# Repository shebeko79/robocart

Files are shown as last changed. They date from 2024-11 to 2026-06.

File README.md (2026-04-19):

### How not to build a robot:
How not to build a robot (https://youtu.be/LK63FLP5XUo)

https://youtu.be/LK63FLP5XUo

### References:
[Field Oriented Control (FOC) for stock hoverboards](https://github.com/EFeru/hoverboard-firmware-hack-FOC)

[Introduction to MaixCAM](https://wiki.sipeed.com/hardware/en/maixcam/maixcam.html)

[MaixCAM System Flashing](https://wiki.sipeed.com/hardware/en/maixcam/os.html)

[MaixPy Quick Start](https://wiki.sipeed.com/maixpy/doc/en/index.html)

[Install RNDIS driver](https://wiki.sipeed.com/hardware/en/maixsense/maixsense-a075v/install_drivers.html)

[Ultralytics quick start](https://docs.ultralytics.com/usage/python/)

[Tracking with Ultralytics](https://docs.ultralytics.com/modes/track/)

[FastSAM](https://docs.ultralytics.com/models/fast-sam/)

[Labeling Application](https://github.com/shebeko79/py_misc/tree/main/yolo_labeling)

[My YOLO train notes](https://github.com/shebeko79/py_misc/tree/main/yolo_train)

[Self-learning Tracker](https://wiki.sipeed.com/maixpy/doc/en/vision/self_learn_detector.html)

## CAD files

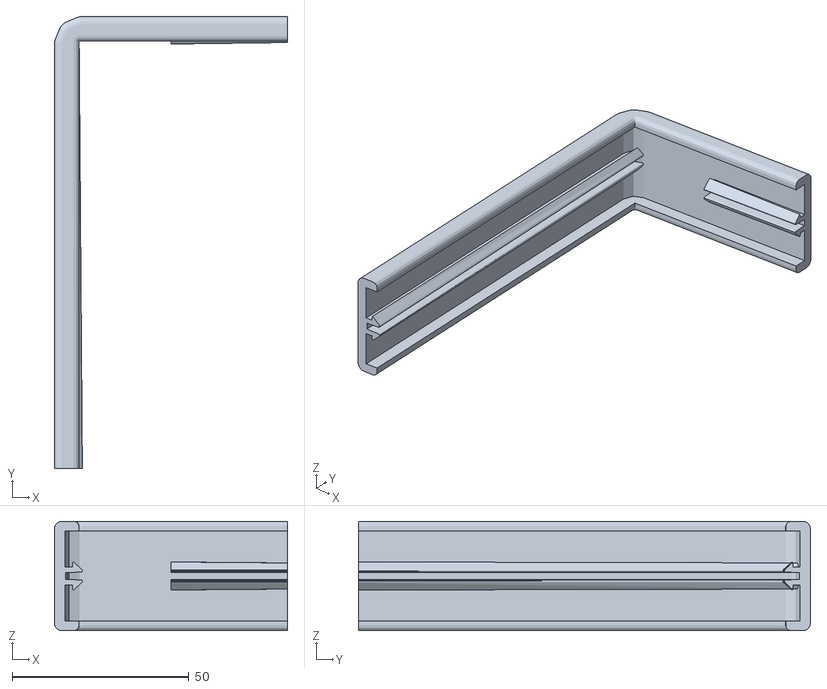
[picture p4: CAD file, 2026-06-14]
model/cover_back.stl
66.1 x 128.0 x 31.0

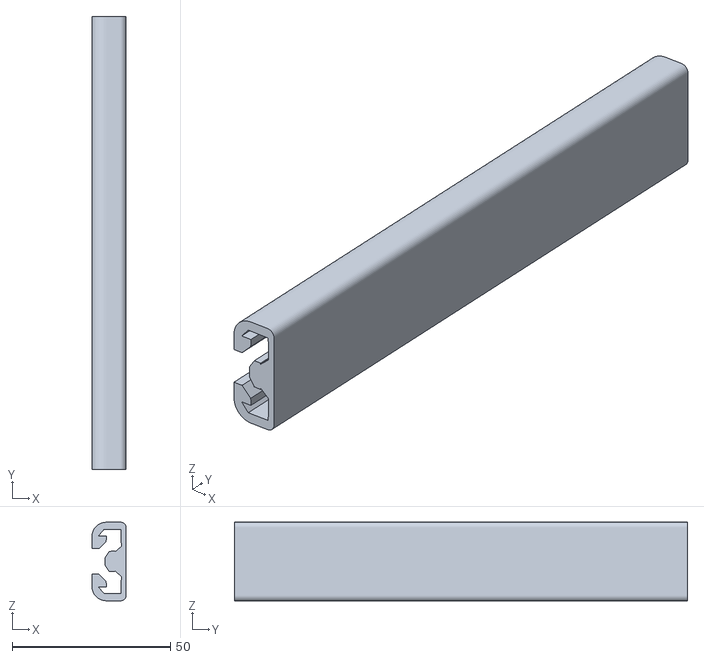
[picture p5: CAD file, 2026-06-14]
model/cover_clipsed_143.stl
10.8 x 143.0 x 24.8

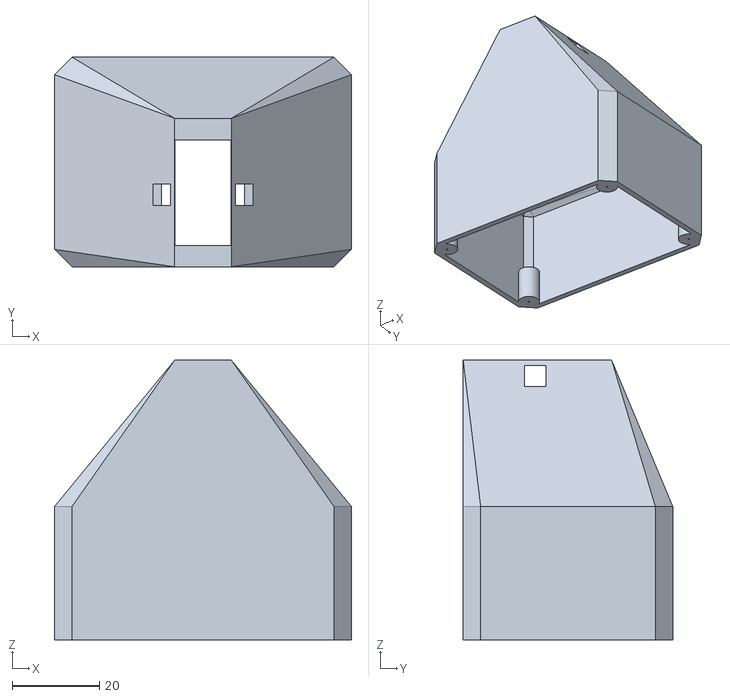
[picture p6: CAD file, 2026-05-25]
model/base.stl
68.0 x 48.0 x 64.0

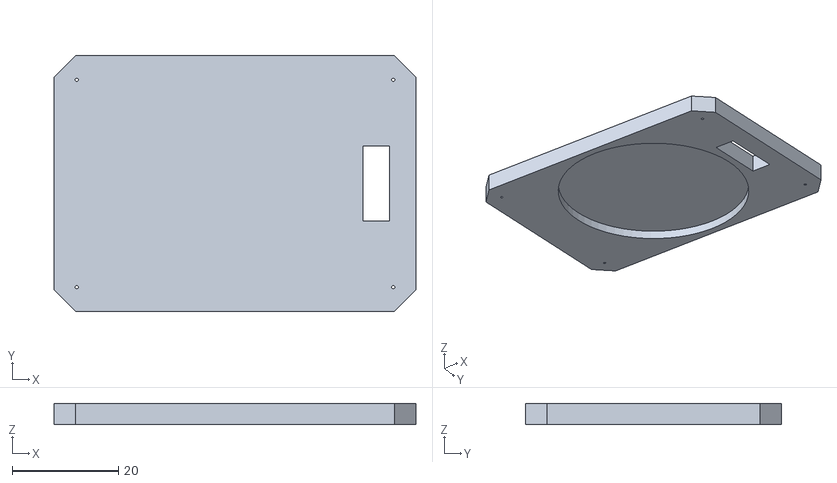
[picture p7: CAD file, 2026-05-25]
model/base_lid.stl
68.0 x 48.0 x 4.00

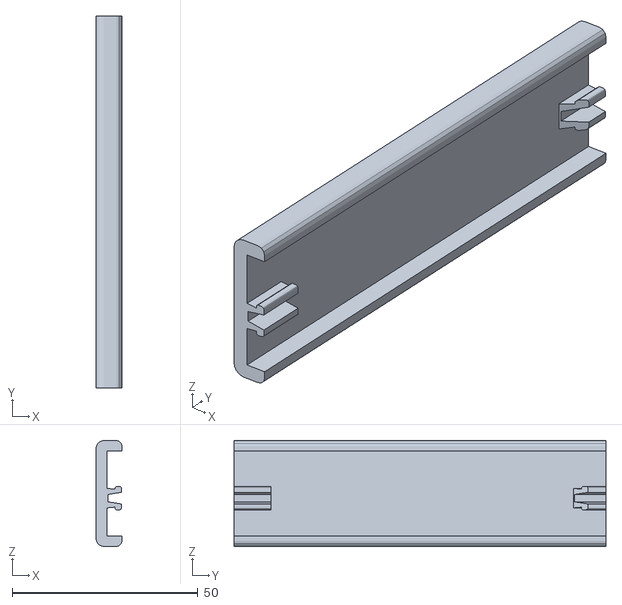
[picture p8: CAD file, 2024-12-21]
model/cover_clipsed_10.stl
7.00 x 100.0 x 28.5

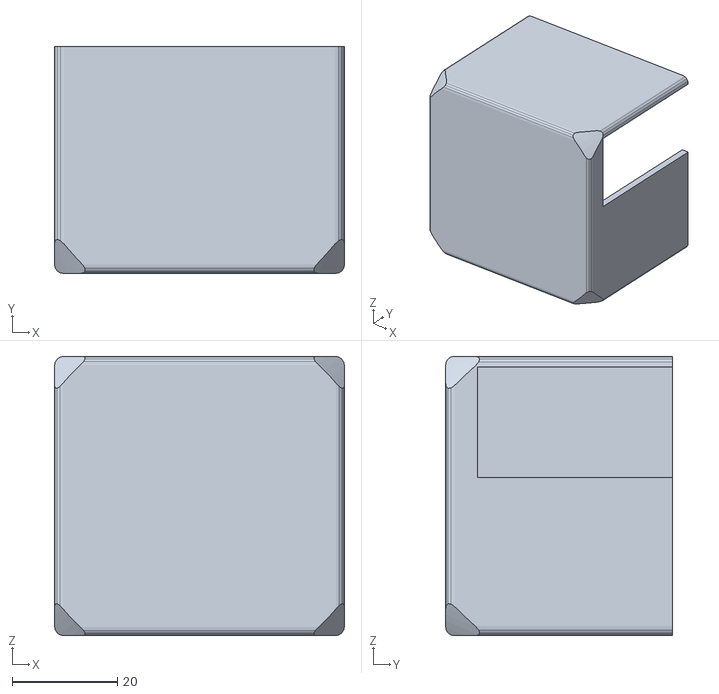
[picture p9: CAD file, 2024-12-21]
model/cover_front.stl
55.0 x 43.0 x 53.0

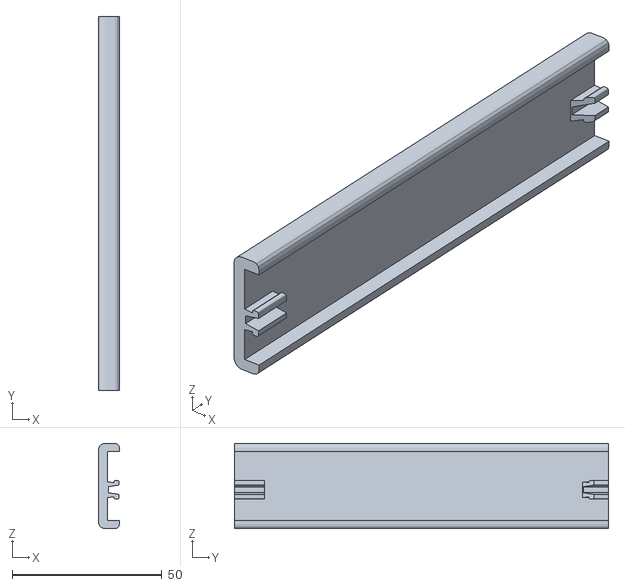
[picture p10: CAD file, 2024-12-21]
model/cover_clipsed_125.stl
7.00 x 125.0 x 28.5

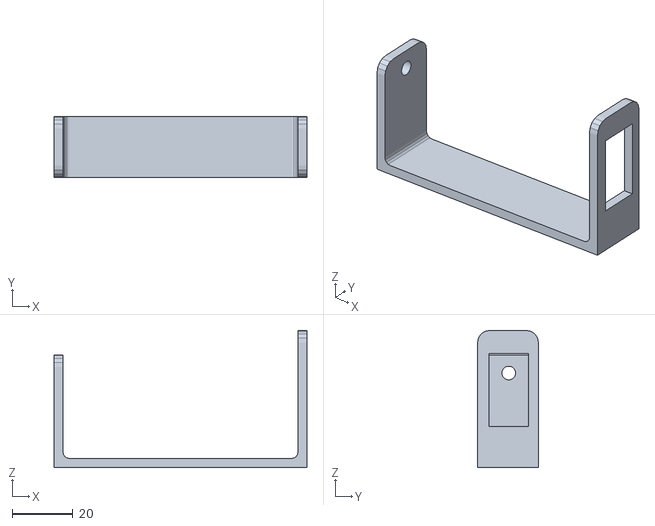
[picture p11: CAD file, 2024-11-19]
model/pan.stl
83.0 x 20.0 x 45.0

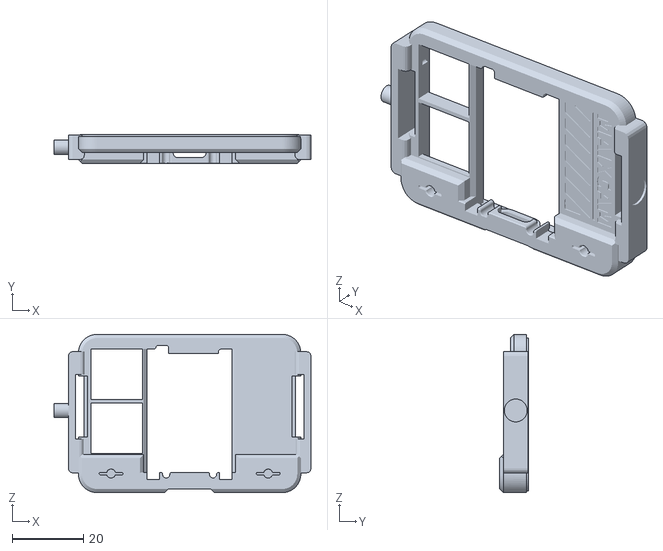
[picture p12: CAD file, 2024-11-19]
model/tilt.stl
72.0 x 8.00 x 44.3

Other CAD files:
model/2020_cover.blend
model/pantilt.blend

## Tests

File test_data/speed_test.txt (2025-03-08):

;0kg free wheel
L: time=285560 cur_speed=0.00 PWM=0.10
L: time=285611 cur_speed=0.02 PWM=0.10
L: time=285660 cur_speed=0.08 PWM=0.10
L: time=285710 cur_speed=0.14 PWM=0.10
L: time=285760 cur_speed=0.21 PWM=0.10
L: time=285810 cur_speed=0.28 PWM=0.10
L: time=285860 cur_speed=0.33 PWM=0.10
L: time=285910 cur_speed=0.40 PWM=0.10
L: time=285960 cur_speed=0.47 PWM=0.10
L: time=286010 cur_speed=0.53 PWM=0.10
L: time=286060 cur_speed=0.60 PWM=0.10
L: time=286110 cur_speed=0.65 PWM=0.10
L: time=286160 cur_speed=0.65 PWM=0.10
L: time=286210 cur_speed=0.65 PWM=0.10
L: time=286260 cur_speed=0.65 PWM=0.10
L: time=286310 cur_speed=0.65 PWM=0.10
L: time=286360 cur_speed=0.65 PWM=0.10
L: time=286410 cur_speed=0.65 PWM=0.10
L: time=286460 cur_speed=0.65 PWM=0.10
L: time=286510 cur_speed=0.65 PWM=0.10
L: time=286560 cur_speed=0.65 PWM=0.10
L: time=286610 cur_speed=0.63 PWM=0.10
L: time=286660 cur_speed=0.65 PWM=0.10
L: time=286710 cur_speed=0.65 PWM=0.10
L: time=286760 cur_speed=0.65 PWM=0.10
L: time=286810 cur_speed=0.65 PWM=0.10
L: time=286860 cur_speed=0.65 PWM=0.10
L: time=286910 cur_speed=0.63 PWM=0.10
L: time=286960 cur_speed=0.65 PWM=0.10
L: time=287010 cur_speed=0.65 PWM=0.10
L: time=287060 cur_speed=0.65 PWM=0.10
L: time=287110 cur_speed=0.65 PWM=0.10
L: time=287160 cur_speed=0.65 PWM=0.10
L: time=287210 cur_speed=0.65 PWM=0.10
L: time=287260 cur_speed=0.65 PWM=0.10
L: time=287310 cur_speed=0.65 PWM=0.10
L: time=287360 cur_speed=0.65 PWM=0.10
L: time=287410 cur_speed=0.65 PWM=0.10
L: time=287460 cur_speed=0.65 PWM=0.10
L: time=287510 cur_speed=0.63 PWM=0.10
L: time=287560 cur_speed=0.65 PWM=0.00
L: time=287610 cur_speed=0.63 PWM=0.00
L: time=287660 cur_speed=0.61 PWM=0.00
L: time=287710 cur_speed=0.60 PWM=0.00
L: time=287760 cur_speed=0.55 PWM=0.00
L: time=287810 cur_speed=0.51 PWM=0.00
L: time=287860 cur_speed=0.44 PWM=0.00
L: time=287910 cur_speed=0.37 PWM=0.00
L: time=287960 cur_speed=0.31 PWM=0.00
L: time=288010 cur_speed=0.24 PWM=0.00
L: time=288060 cur_speed=0.17 PWM=0.00
L: time=288110 cur_speed=0.12 PWM=0.00
L: time=288160 cur_speed=0.07 PWM=0.00
L: time=288210 cur_speed=0.03 PWM=0.00
L: time=288260 cur_speed=0.01 PWM=0.00

L: time=293461 cur_speed=0.00 PWM=0.20
L: time=293512 cur_speed=0.02 PWM=0.20
L: time=293562 cur_speed=0.12 PWM=0.20
L: time=293612 cur_speed=0.22 PWM=0.20
L: time=293662 cur_speed=0.33 PWM=0.20
L: time=293712 cur_speed=0.46 PWM=0.20
L: time=293762 cur_speed=0.58 PWM=0.20
L: time=293812 cur_speed=0.69 PWM=0.20
L: time=293862 cur_speed=0.81 PWM=0.20
L: time=293912 cur_speed=0.92 PWM=0.20
L: time=293962 cur_speed=1.04 PWM=0.20
L: time=294012 cur_speed=1.13 PWM=0.20
L: time=294062 cur_speed=1.14 PWM=0.20
L: time=294112 cur_speed=1.14 PWM=0.20
L: time=294162 cur_speed=1.15 PWM=0.20
L: time=294212 cur_speed=1.15 PWM=0.20
L: time=294262 cur_speed=1.15 PWM=0.20
L: time=294312 cur_speed=1.15 PWM=0.20
L: time=294362 cur_speed=1.15 PWM=0.20
L: time=294412 cur_speed=1.15 PWM=0.20
L: time=294462 cur_speed=1.15 PWM=0.20
L: time=294512 cur_speed=1.15 PWM=0.20
L: time=294562 cur_speed=1.15 PWM=0.20
L: time=294612 cur_speed=1.15 PWM=0.20
L: time=294662 cur_speed=1.15 PWM=0.20
L: time=294712 cur_speed=1.15 PWM=0.20
L: time=294762 cur_speed=1.15 PWM=0.20
L: time=294812 cur_speed=1.15 PWM=0.20
L: time=294862 cur_speed=1.15 PWM=0.20
L: time=294912 cur_speed=1.15 PWM=0.20
L: time=294962 cur_speed=1.15 PWM=0.20
L: time=295012 cur_speed=1.15 PWM=0.20
L: time=295062 cur_speed=1.15 PWM=0.20
L: time=295112 cur_speed=1.15 PWM=0.20
L: time=295162 cur_speed=1.15 PWM=0.20
L: time=295212 cur_speed=1.15 PWM=0.20
L: time=295262 cur_speed=1.15 PWM=0.20
L: time=295312 cur_speed=1.15 PWM=0.20
L: time=295362 cur_speed=1.15 PWM=0.20
L: time=295412 cur_speed=1.15 PWM=0.20
L: time=295462 cur_speed=1.15 PWM=0.00
L: time=295512 cur_speed=1.14 PWM=0.00
L: time=295562 cur_speed=1.12 PWM=0.00
L: time=295612 cur_speed=1.09 PWM=0.00
L: time=295662 cur_speed=1.05 PWM=0.00
L: time=295712 cur_speed=0.98 PWM=0.00
L: time=295762 cur_speed=0.91 PWM=0.00
L: time=295812 cur_speed=0.83 PWM=0.00
L: time=295862 cur_speed=0.73 PWM=0.00
L: time=295912 cur_speed=0.62 PWM=0.00
L: time=295962 cur_speed=0.50 PWM=0.00
L: time=296012 cur_speed=0.39 PWM=0.00
L: time=296062 cur_speed=0.30 PWM=0.00
L: time=296112 cur_speed=0.22 PWM=0.00
L: time=296162 cur_speed=0.15 PWM=0.00
L: time=296212 cur_speed=0.09 PWM=0.00
L: time=296262 cur_speed=0.06 PWM=0.00
L: time=296312 cur_speed=0.02 PWM=0.00
L: time=296362 cur_speed=0.01 PWM=0.00

L: time=299913 cur_speed=0.00 PWM=0.30
L: time=299964 cur_speed=0.02 PWM=0.30
L: time=300014 cur_speed=0.13 PWM=0.30
L: time=300064 cur_speed=0.28 PWM=0.30
L: time=300114 cur_speed=0.44 PWM=0.30
L: time=300164 cur_speed=0.61 PWM=0.30
L: time=300214 cur_speed=0.77 PWM=0.30
L: time=300264 cur_speed=0.93 PWM=0.30
L: time=300314 cur_speed=1.09 PWM=0.30
L: time=300364 cur_speed=1.27 PWM=0.30
L: time=300414 cur_speed=1.43 PWM=0.30
L: time=300464 cur_speed=1.57 PWM=0.30
L: time=300514 cur_speed=1.61 PWM=0.30
L: time=300564 cur_speed=1.64 PWM=0.30
L: time=300614 cur_speed=1.64 PWM=0.30
L: time=300664 cur_speed=1.63 PWM=0.30
L: time=300714 cur_speed=1.63 PWM=0.30
L: time=300764 cur_speed=1.64 PWM=0.30
L: time=300814 cur_speed=1.64 PWM=0.30
L: time=300864 cur_speed=1.63 PWM=0.30
L: time=300913 cur_speed=1.63 PWM=0.30
L: time=300964 cur_speed=1.64 PWM=0.30
L: time=301014 cur_speed=1.64 PWM=0.30
L: time=301064 cur_speed=1.63 PWM=0.30
L: time=301114 cur_speed=1.63 PWM=0.30
L: time=301164 cur_speed=1.64 PWM=0.30
L: time=301214 cur_speed=1.63 PWM=0.30
L: time=301264 cur_speed=1.63 PWM=0.30
L: time=301314 cur_speed=1.63 PWM=0.30
L: time=301364 cur_speed=1.64 PWM=0.30
L: time=301414 cur_speed=1.64 PWM=0.30
L: time=301464 cur_speed=1.63 PWM=0.30
L: time=301514 cur_speed=1.63 PWM=0.30
L: time=301564 cur_speed=1.64 PWM=0.30
L: time=301614 cur_speed=1.64 PWM=0.30
L: time=301664 cur_speed=1.63 PWM=0.30
L: time=301714 cur_speed=1.64 PWM=0.30
L: time=301764 cur_speed=1.64 PWM=0.30
L: time=301814 cur_speed=1.63 PWM=0.30
L: time=301864 cur_speed=1.63 PWM=0.30
L: time=301913 cur_speed=1.63 PWM=0.00
L: time=301963 cur_speed=1.63 PWM=0.00
L: time=302013 cur_speed=1.61 PWM=0.00
L: time=302063 cur_speed=1.57 PWM=0.00
L: time=302113 cur_speed=1.52 PWM=0.00
L: time=302163 cur_speed=1.46 PWM=0.00
L: time=302213 cur_speed=1.37 PWM=0.00
L: time=302263 cur_speed=1.28 PWM=0.00
L: time=302313 cur_speed=1.18 PWM=0.00
L: time=302364 cur_speed=1.06 PWM=0.00
L: time=302413 cur_speed=0.92 PWM=0.00
L: time=302463 cur_speed=0.80 PWM=0.00
L: time=302513 cur_speed=0.66 PWM=0.00
L: time=302563 cur_speed=0.53 PWM=0.00
L: time=302613 cur_speed=0.41 PWM=0.00
L: time=302663 cur_speed=0.32 PWM=0.00
L: time=302713 cur_speed=0.23 PWM=0.00
L: time=302763 cur_speed=0.16 PWM=0.00
L: time=302813 cur_speed=0.10 PWM=0.00
L: time=302863 cur_speed=0.06 PWM=0.00
L: time=302913 cur_speed=0.02 PWM=0.00
L: time=302963 cur_speed=0.01 PWM=0.00

L: time=307314 cur_speed=0.00 PWM=0.40
L: time=307364 cur_speed=0.02 PWM=0.40
L: time=307414 cur_speed=0.13 PWM=0.40
L: time=307464 cur_speed=0.31 PWM=0.40
L: time=307514 cur_speed=0.52 PWM=0.40
L: time=307564 cur_speed=0.73 PWM=0.40
L: time=307614 cur_speed=0.95 PWM=0.40
L: time=307664 cur_speed=1.15 PWM=0.40
L: time=307714 cur_speed=1.37 PWM=0.40
L: time=307764 cur_speed=1.58 PWM=0.40
L: time=307814 cur_speed=1.79 PWM=0.40
L: time=307864 cur_speed=1.98 PWM=0.40
L: time=307914 cur_speed=2.07 PWM=0.40
L: time=307964 cur_speed=2.11 PWM=0.40
L: time=308014 cur_speed=2.11 PWM=0.40
L: time=308064 cur_speed=2.11 PWM=0.40
L: time=308114 cur_speed=2.11 PWM=0.40
L: time=308164 cur_speed=2.11 PWM=0.40
L: time=308214 cur_speed=2.10 PWM=0.40
L: time=308264 cur_speed=2.11 PWM=0.40
L: time=308314 cur_speed=2.11 PWM=0.40
L: time=308364 cur_speed=2.10 PWM=0.40
L: time=308414 cur_speed=2.11 PWM=0.40
L: time=308464 cur_speed=2.11 PWM=0.40
L: time=308514 cur_speed=2.11 PWM=0.40
L: time=308564 cur_speed=2.11 PWM=0.40
L: time=308614 cur_speed=2.10 PWM=0.40
L: time=308664 cur_speed=2.11 PWM=0.40
L: time=308714 cur_speed=2.11 PWM=0.40
L: time=308764 cur_speed=2.11 PWM=0.40
L: time=308814 cur_speed=2.11 PWM=0.40
L: time=308864 cur_speed=2.11 PWM=0.40
L: time=308914 cur_speed=2.11 PWM=0.40
L: time=308964 cur_speed=2.11 PWM=0.40
L: time=309014 cur_speed=2.10 PWM=0.40
L: time=309064 cur_speed=2.11 PWM=0.40
L: time=309114 cur_speed=2.11 PWM=0.40
L: time=309164 cur_speed=2.11 PWM=0.40
L: time=309214 cur_speed=2.11 PWM=0.40
L: time=309264 cur_speed=2.11 PWM=0.40
L: time=309314 cur_speed=2.11 PWM=0.00
L: time=309364 cur_speed=2.11 PWM=0.00
L: time=309414 cur_speed=2.07 PWM=0.00
L: time=309464 cur_speed=2.04 PWM=0.00
L: time=309514 cur_speed=1.99 PWM=0.00
L: time=309564 cur_speed=1.92 PWM=0.00
L: time=309614 cur_speed=1.84 PWM=0.00
L: time=309664 cur_speed=1.73 PWM=0.00
L: time=309714 cur_speed=1.63 PWM=0.00
L: time=309764 cur_speed=1.51 PWM=0.00
L: time=309814 cur_speed=1.36 PWM=0.00
L: time=309864 cur_speed=1.22 PWM=0.00
L: time=309914 cur_speed=1.07 PWM=0.00
L: time=309964 cur_speed=0.93 PWM=0.00
L: time=310014 cur_speed=0.78 PWM=0.00
L: time=310064 cur_speed=0.66 PWM=0.00
L: time=310114 cur_speed=0.53 PWM=0.00
L: time=310164 cur_speed=0.41 PWM=0.00
L: time=310214 cur_speed=0.32 PWM=0.00
L: time=310264 cur_speed=0.23 PWM=0.00
L: time=310314 cur_speed=0.16 PWM=0.00
L: time=310364 cur_speed=0.10 PWM=0.00
L: time=310414 cur_speed=0.06 PWM=0.00
L: time=310464 cur_speed=0.02 PWM=0.00

L: time=314765 cur_speed=0.00 PWM=0.50
L: time=314816 cur_speed=0.02 PWM=0.50
L: time=314866 cur_speed=0.13 PWM=0.50
L: time=314916 cur_speed=0.33 PWM=0.50
L: time=314965 cur_speed=0.58 PWM=0.50
L: time=315015 cur_speed=0.83 PWM=0.50
L: time=315065 cur_speed=1.08 PWM=0.50
L: time=315116 cur_speed=1.34 PWM=0.50
L: time=315165 cur_speed=1.59 PWM=0.50
L: time=315216 cur_speed=1.84 PWM=0.50
L: time=315266 cur_speed=2.10 PWM=0.50
L: time=315315 cur_speed=2.33 PWM=0.50
L: time=315365 cur_speed=2.47 PWM=0.50
L: time=315415 cur_speed=2.52 PWM=0.50
L: time=315465 cur_speed=2.54 PWM=0.50
L: time=315515 cur_speed=2.54 PWM=0.50
L: time=315565 cur_speed=2.54 PWM=0.50
L: time=315615 cur_speed=2.54 PWM=0.50
L: time=315665 cur_speed=2.54 PWM=0.50
L: time=315715 cur_speed=2.52 PWM=0.50
L: time=315765 cur_speed=2.52 PWM=0.50
L: time=315815 cur_speed=2.52 PWM=0.50
L: time=315865 cur_speed=2.52 PWM=0.50
L: time=315915 cur_speed=2.52 PWM=0.50
L: time=315965 cur_speed=2.52 PWM=0.50
L: time=316015 cur_speed=2.52 PWM=0.50
L: time=316065 cur_speed=2.52 PWM=0.50
L: time=316115 cur_speed=2.52 PWM=0.50
L: time=316165 cur_speed=2.52 PWM=0.50
L: time=316215 cur_speed=2.52 PWM=0.50
L: time=316265 cur_speed=2.52 PWM=0.50
L: time=316315 cur_speed=2.52 PWM=0.50
L: time=316365 cur_speed=2.52 PWM=0.50
L: time=316415 cur_speed=2.52 PWM=0.50
L: time=316465 cur_speed=2.52 PWM=0.50
L: time=316515 cur_speed=2.54 PWM=0.50
L: time=316565 cur_speed=2.52 PWM=0.50
L: time=316616 cur_speed=2.52 PWM=0.50
L: time=316665 cur_speed=2.54 PWM=0.50
L: time=316715 cur_speed=2.54 PWM=0.50
L: time=316765 cur_speed=2.54 PWM=0.00
L: time=316815 cur_speed=2.52 PWM=0.00
L: time=316865 cur_speed=2.50 PWM=0.00
L: time=316915 cur_speed=2.47 PWM=0.00
L: time=316965 cur_speed=2.41 PWM=0.00
L: time=317015 cur_speed=2.34 PWM=0.00
L: time=317065 cur_speed=2.25 PWM=0.00
L: time=317115 cur_speed=2.14 PWM=0.00
L: time=317165 cur_speed=2.02 PWM=0.00
L: time=317215 cur_speed=1.89 PWM=0.00
L: time=317265 cur_speed=1.74 PWM=0.00
L: time=317315 cur_speed=1.58 PWM=0.00
L: time=317365 cur_speed=1.42 PWM=0.00
L: time=317415 cur_speed=1.27 PWM=0.00
L: time=317465 cur_speed=1.13 PWM=0.00
L: time=317515 cur_speed=0.98 PWM=0.00
L: time=317565 cur_speed=0.84 PWM=0.00
L: time=317615 cur_speed=0.69 PWM=0.00
L: time=317665 cur_speed=0.58 PWM=0.00
L: time=317715 cur_speed=0.46 PWM=0.00
L: time=317765 cur_speed=0.36 PWM=0.00
L: time=317815 cur_speed=0.27 PWM=0.00
L: time=317865 cur_speed=0.20 PWM=0.00
L: time=317915 cur_speed=0.13 PWM=0.00
L: time=317965 cur_speed=0.08 PWM=0.00
L: time=318015 cur_speed=0.05 PWM=0.00
L: time=318065 cur_speed=0.02 PWM=0.00
L: time=318115 cur_speed=0.02 PWM=0.00

L: time=324166 cur_speed=0.00 PWM=0.60
L: time=324217 cur_speed=0.02 PWM=0.60
L: time=324267 cur_speed=0.13 PWM=0.60
L: time=324316 cur_speed=0.33 PWM=0.60
L: time=324367 cur_speed=0.61 PWM=0.60
L: time=324417 cur_speed=0.90 PWM=0.60
L: time=324467 cur_speed=1.20 PWM=0.60
L: time=324516 cur_speed=1.50 PWM=0.60
L: time=324566 cur_speed=1.79 PWM=0.60
L: time=324617 cur_speed=2.09 PWM=0.60
L: time=324667 cur_speed=2.39 PWM=0.60
L: time=324717 cur_speed=2.66 PWM=0.60
L: time=324766 cur_speed=2.85 PWM=0.60
L: time=324816 cur_speed=2.94 PWM=0.60
L: time=324867 cur_speed=2.96 PWM=0.60
L: time=324917 cur_speed=2.97 PWM=0.60
L: time=324967 cur_speed=2.96 PWM=0.60
L: time=325017 cur_speed=2.96 PWM=0.60
L: time=325067 cur_speed=2.96 PWM=0.60
L: time=325117 cur_speed=2.97 PWM=0.60
L: time=325167 cur_speed=2.96 PWM=0.60
L: time=325216 cur_speed=2.96 PWM=0.60
L: time=325267 cur_speed=2.96 PWM=0.60
L: time=325317 cur_speed=2.97 PWM=0.60
L: time=325366 cur_speed=2.96 PWM=0.60
L: time=325417 cur_speed=2.96 PWM=0.60
L: time=325466 cur_speed=2.96 PWM=0.60
L: time=325516 cur_speed=2.96 PWM=0.60
L: time=325567 cur_speed=2.96 PWM=0.60
L: time=325616 cur_speed=2.96 PWM=0.60
L: time=325667 cur_speed=2.97 PWM=0.60
L: time=325717 cur_speed=2.97 PWM=0.60
L: time=325767 cur_speed=2.96 PWM=0.60
L: time=325817 cur_speed=2.96 PWM=0.60
L: time=325867 cur_speed=2.96 PWM=0.60
L: time=325917 cur_speed=2.96 PWM=0.60
L: time=325967 cur_speed=2.96 PWM=0.60
L: time=326017 cur_speed=2.96 PWM=0.60
L: time=326067 cur_speed=2.96 PWM=0.60
L: time=326116 cur_speed=2.96 PWM=0.60
L: time=326166 cur_speed=2.96 PWM=0.00
L: time=326216 cur_speed=2.95 PWM=0.00
L: time=326266 cur_speed=2.93 PWM=0.00
L: time=326316 cur_speed=2.89 PWM=0.00
L: time=326366 cur_speed=2.84 PWM=0.00
L: time=326416 cur_speed=2.75 PWM=0.00
L: time=326466 cur_speed=2.66 PWM=0.00
L: time=326516 cur_speed=2.56 PWM=0.00
L: time=326566 cur_speed=2.42 PWM=0.00
L: time=326616 cur_speed=2.28 PWM=0.00
L: time=326666 cur_speed=2.13 PWM=0.00
L: time=326716 cur_speed=1.95 PWM=0.00
L: time=326766 cur_speed=1.80 PWM=0.00
L: time=326816 cur_speed=1.63 PWM=0.00
L: time=326866 cur_speed=1.48 PWM=0.00
L: time=326916 cur_speed=1.31 PWM=0.00
L: time=326966 cur_speed=1.16 PWM=0.00
L: time=327016 cur_speed=1.03 PWM=0.00
L: time=327066 cur_speed=0.89 PWM=0.00
L: time=327116 cur_speed=0.75 PWM=0.00
L: time=327166 cur_speed=0.62 PWM=0.00
L: time=327216 cur_speed=0.51 PWM=0.00
L: time=327266 cur_speed=0.39 PWM=0.00
L: time=327316 cur_speed=0.30 PWM=0.00
L: time=327366 cur_speed=0.22 PWM=0.00
L: time=327416 cur_speed=0.15 PWM=0.00
L: time=327466 cur_speed=0.10 PWM=0.00
L: time=327516 cur_speed=0.06 PWM=0.00
L: time=327566 cur_speed=0.02 PWM=0.00
L: time=327616 cur_speed=0.01 PWM=0.00

L: time=331117 cur_speed=0.00 PWM=0.70
L: time=331167 cur_speed=0.01 PWM=0.70
L: time=331217 cur_speed=0.13 PWM=0.70
L: time=331267 cur_speed=0.33 PWM=0.70
L: time=331317 cur_speed=0.62 PWM=0.70
L: time=331367 cur_speed=0.96 PWM=0.70
L: time=331417 cur_speed=1.29 PWM=0.70
L: time=331467 cur_speed=1.63 PWM=0.70
L: time=331517 cur_speed=1.96 PWM=0.70
L: time=331567 cur_speed=2.29 PWM=0.70
L: time=331617 cur_speed=2.63 PWM=0.70
L: time=331667 cur_speed=2.95 PWM=0.70
L: time=331717 cur_speed=3.16 PWM=0.70
L: time=331767 cur_speed=3.26 PWM=0.70
L: time=331817 cur_speed=3.28 PWM=0.70
L: time=331867 cur_speed=3.30 PWM=0.70
L: time=331917 cur_speed=3.31 PWM=0.70
L: time=331967 cur_speed=3.31 PWM=0.70
L: time=332017 cur_speed=3.30 PWM=0.70
L: time=332067 cur_speed=3.30 PWM=0.70
L: time=332117 cur_speed=3.30 PWM=0.70
L: time=332167 cur_speed=3.31 PWM=0.70
L: time=332217 cur_speed=3.31 PWM=0.70
L: time=332267 cur_speed=3.30 PWM=0.70
L: time=332317 cur_speed=3.30 PWM=0.70
L: time=332367 cur_speed=3.30 PWM=0.70
L: time=332417 cur_speed=3.31 PWM=0.70
L: time=332467 cur_speed=3.31 PWM=0.70
L: time=332517 cur_speed=3.30 PWM=0.70
L: time=332567 cur_speed=3.30 PWM=0.70
L: time=332617 cur_speed=3.30 PWM=0.70
L: time=332667 cur_speed=3.31 PWM=0.70
L: time=332717 cur_speed=3.31 PWM=0.70
L: time=332767 cur_speed=3.30 PWM=0.70
L: time=332817 cur_speed=3.30 PWM=0.70
L: time=332867 cur_speed=3.30 PWM=0.70
L: time=332917 cur_speed=3.31 PWM=0.70
L: time=332967 cur_speed=3.31 PWM=0.70
L: time=333017 cur_speed=3.30 PWM=0.70
L: time=333067 cur_speed=3.30 PWM=0.70
L: time=333117 cur_speed=3.30 PWM=0.00
L: time=333167 cur_speed=3.30 PWM=0.00
L: time=333217 cur_speed=3.27 PWM=0.00
L: time=333267 cur_speed=3.23 PWM=0.00
L: time=333317 cur_speed=3.16 PWM=0.00
L: time=333367 cur_speed=3.08 PWM=0.00
L: time=333417 cur_speed=2.99 PWM=0.00
L: time=333467 cur_speed=2.87 PWM=0.00
L: time=333517 cur_speed=2.72 PWM=0.00
L: time=333567 cur_speed=2.58 PWM=0.00
L: time=333617 cur_speed=2.41 PWM=0.00
L: time=333667 cur_speed=2.25 PWM=0.00
L: time=333717 cur_speed=2.07 PWM=0.00
L: time=333767 cur_speed=1.90 PWM=0.00
L: time=333817 cur_speed=1.73 PWM=0.00
L: time=333867 cur_speed=1.59 PWM=0.00
L: time=333917 cur_speed=1.42 PWM=0.00
L: time=333967 cur_speed=1.28 PWM=0.00
L: time=334017 cur_speed=1.12 PWM=0.00
L: time=334067 cur_speed=0.98 PWM=0.00
L: time=334117 cur_speed=0.84 PWM=0.00
L: time=334167 cur_speed=0.70 PWM=0.00
L: time=334217 cur_speed=0.56 PWM=0.00
L: time=334267 cur_speed=0.45 PWM=0.00
L: time=334317 cur_speed=0.35 PWM=0.00
L: time=334367 cur_speed=0.25 PWM=0.00
L: time=334417 cur_speed=0.17 PWM=0.00
L: time=334467 cur_speed=0.12 PWM=0.00
L: time=334517 cur_speed=0.07 PWM=0.00
L: time=334567 cur_speed=0.03 PWM=0.00
L: time=334617 cur_speed=0.01 PWM=0.00

L: time=338522 cur_speed=0.00 PWM=0.80
L: time=338573 cur_speed=0.02 PWM=0.80
L: time=338623 cur_speed=0.13 PWM=0.80
L: time=338673 cur_speed=0.33 PWM=0.80
L: time=338723 cur_speed=0.63 PWM=0.80
L: time=338773 cur_speed=0.99 PWM=0.80
L: time=338823 cur_speed=1.36 PWM=0.80
L: time=338873 cur_speed=1.74 PWM=0.80
L: time=338923 cur_speed=2.11 PWM=0.80
L: time=338973 cur_speed=2.49 PWM=0.80
L: time=339023 cur_speed=2.86 PWM=0.80
L: time=339073 cur_speed=3.22 PWM=0.80
L: time=339122 cur_speed=3.47 PWM=0.80
L: time=339173 cur_speed=3.63 PWM=0.80
L: time=339223 cur_speed=3.69 PWM=0.80
L: time=339273 cur_speed=3.71 PWM=0.80
L: time=339323 cur_speed=3.71 PWM=0.80
L: time=339373 cur_speed=3.71 PWM=0.80
L: time=339423 cur_speed=3.72 PWM=0.80
L: time=339473 cur_speed=3.71 PWM=0.80
L: time=339523 cur_speed=3.72 PWM=0.80
L: time=339573 cur_speed=3.71 PWM=0.80
L: time=339623 cur_speed=3.72 PWM=0.80
L: time=339673 cur_speed=3.71 PWM=0.80
L: time=339723 cur_speed=3.72 PWM=0.80
L: time=339773 cur_speed=3.71 PWM=0.80
L: time=339823 cur_speed=3.72 PWM=0.80
L: time=339872 cur_speed=3.71 PWM=0.80
L: time=339923 cur_speed=3.72 PWM=0.80
L: time=339973 cur_speed=3.71 PWM=0.80
L: time=340023 cur_speed=3.72 PWM=0.80
L: time=340073 cur_speed=3.71 PWM=0.80
L: time=340123 cur_speed=3.71 PWM=0.80
L: time=340173 cur_speed=3.71 PWM=0.80
L: time=340223 cur_speed=3.71 PWM=0.80
L: time=340273 cur_speed=3.71 PWM=0.80
L: time=340323 cur_speed=3.71 PWM=0.80
L: time=340373 cur_speed=3.71 PWM=0.80
L: time=340422 cur_speed=3.71 PWM=0.80
L: time=340472 cur_speed=3.71 PWM=0.80
L: time=340522 cur_speed=3.71 PWM=0.00
L: time=340573 cur_speed=3.71 PWM=0.00
L: time=340623 cur_speed=3.68 PWM=0.00
L: time=340672 cur_speed=3.64 PWM=0.00
L: time=340723 cur_speed=3.56 PWM=0.00
L: time=340772 cur_speed=3.48 PWM=0.00
L: time=340822 cur_speed=3.38 PWM=0.00
L: time=340873 cur_speed=3.26 PWM=0.00
L: time=340923 cur_speed=3.11 PWM=0.00
L: time=340973 cur_speed=2.96 PWM=0.00
L: time=341023 cur_speed=2.78 PWM=0.00
L: time=341073 cur_speed=2.59 PWM=0.00
L: time=341123 cur_speed=2.41 PWM=0.00
L: time=341172 cur_speed=2.25 PWM=0.00
L: time=341222 cur_speed=2.06 PWM=0.00
L: time=341273 cur_speed=1.90 PWM=0.00
L: time=341323 cur_speed=1.74 PWM=0.00
L: time=341372 cur_speed=1.58 PWM=0.00
L: time=341423 cur_speed=1.42 PWM=0.00
L: time=341473 cur_speed=1.28 PWM=0.00
L: time=341523 cur_speed=1.12 PWM=0.00
L: time=341573 cur_speed=0.99 PWM=0.00
L: time=341623 cur_speed=0.84 PWM=0.00
L: time=341673 cur_speed=0.71 PWM=0.00
L: time=341722 cur_speed=0.59 PWM=0.00
L: time=341773 cur_speed=0.47 PWM=0.00
L: time=341823 cur_speed=0.37 PWM=0.00
L: time=341872 cur_speed=0.28 PWM=0.00
L: time=341922 cur_speed=0.20 PWM=0.00
L: time=341972 cur_speed=0.14 PWM=0.00
L: time=342023 cur_speed=0.08 PWM=0.00
L: time=342073 cur_speed=0.05 PWM=0.00
L: time=342122 cur_speed=0.01 PWM=0.00

L: time=346473 cur_speed=0.00 PWM=0.90
L: time=346524 cur_speed=0.02 PWM=0.90
L: time=346574 cur_speed=0.13 PWM=0.90
L: time=346624 cur_speed=0.33 PWM=0.90
L: time=346674 cur_speed=0.63 PWM=0.90
L: time=346724 cur_speed=1.01 PWM=0.90
L: time=346774 cur_speed=1.42 PWM=0.90
L: time=346824 cur_speed=1.82 PWM=0.90
L: time=346874 cur_speed=2.24 PWM=0.90
L: time=346923 cur_speed=2.65 PWM=0.90
L: time=346974 cur_speed=3.05 PWM=0.90
L: time=347024 cur_speed=3.45 PWM=0.90
L: time=347074 cur_speed=3.75 PWM=0.90
L: time=347124 cur_speed=3.94 PWM=0.90
L: time=347174 cur_speed=4.03 PWM=0.90
L: time=347224 cur_speed=4.08 PWM=0.90
L: time=347274 cur_speed=4.09 PWM=0.90
L: time=347324 cur_speed=4.09 PWM=0.90
L: time=347374 cur_speed=4.08 PWM=0.90
L: time=347424 cur_speed=4.09 PWM=0.90
L: time=347474 cur_speed=4.09 PWM=0.90
L: time=347524 cur_speed=4.09 PWM=0.90
L: time=347574 cur_speed=4.08 PWM=0.90
L: time=347624 cur_speed=4.09 PWM=0.90
L: time=347673 cur_speed=4.09 PWM=0.90
L: time=347724 cur_speed=4.09 PWM=0.90
L: time=347774 cur_speed=4.08 PWM=0.90
L: time=347824 cur_speed=4.09 PWM=0.90
L: time=347874 cur_speed=4.09 PWM=0.90
L: time=347924 cur_speed=4.09 PWM=0.90
L: time=347974 cur_speed=4.09 PWM=0.90
L: time=348024 cur_speed=4.09 PWM=0.90
L: time=348074 cur_speed=4.09 PWM=0.90
L: time=348124 cur_speed=4.08 PWM=0.90
L: time=348174 cur_speed=4.09 PWM=0.90
L: time=348224 cur_speed=4.09 PWM=0.90
L: time=348274 cur_speed=4.09 PWM=0.90
L: time=348324 cur_speed=4.08 PWM=0.90
L: time=348374 cur_speed=4.09 PWM=0.90
L: time=348424 cur_speed=4.09 PWM=0.90
L: time=348473 cur_speed=4.09 PWM=0.00
L: time=348523 cur_speed=4.08 PWM=0.00
L: time=348573 cur_speed=4.06 PWM=0.00
L: time=348623 cur_speed=4.01 PWM=0.00
L: time=348673 cur_speed=3.93 PWM=0.00
L: time=348723 cur_speed=3.84 PWM=0.00
L: time=348773 cur_speed=3.75 PWM=0.00
L: time=348823 cur_speed=3.61 PWM=0.00
L: time=348873 cur_speed=3.46 PWM=0.00
L: time=348923 cur_speed=3.30 PWM=0.00
L: time=348973 cur_speed=3.11 PWM=0.00
L: time=349023 cur_speed=2.93 PWM=0.00
L: time=349073 cur_speed=2.73 PWM=0.00
L: time=349123 cur_speed=2.55 PWM=0.00
L: time=349173 cur_speed=2.37 PWM=0.00
L: time=349223 cur_speed=2.19 PWM=0.00
L: time=349273 cur_speed=2.02 PWM=0.00
L: time=349323 cur_speed=1.84 PWM=0.00
L: time=349373 cur_speed=1.68 PWM=0.00
L: time=349423 cur_speed=1.53 PWM=0.00
L: time=349474 cur_speed=1.37 PWM=0.00
L: time=349523 cur_speed=1.22 PWM=0.00
L: time=349574 cur_speed=1.07 PWM=0.00
L: time=349623 cur_speed=0.93 PWM=0.00
L: time=349674 cur_speed=0.81 PWM=0.00
L: time=349723 cur_speed=0.66 PWM=0.00
L: time=349773 cur_speed=0.53 PWM=0.00
L: time=349823 cur_speed=0.41 PWM=0.00
L: time=349874 cur_speed=0.31 PWM=0.00
L: time=349923 cur_speed=0.23 PWM=0.00
L: time=349973 cur_speed=0.16 PWM=0.00
L: time=350023 cur_speed=0.09 PWM=0.00
L: time=350073 cur_speed=0.06 PWM=0.00
L: time=350123 cur_speed=0.02 PWM=0.00
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

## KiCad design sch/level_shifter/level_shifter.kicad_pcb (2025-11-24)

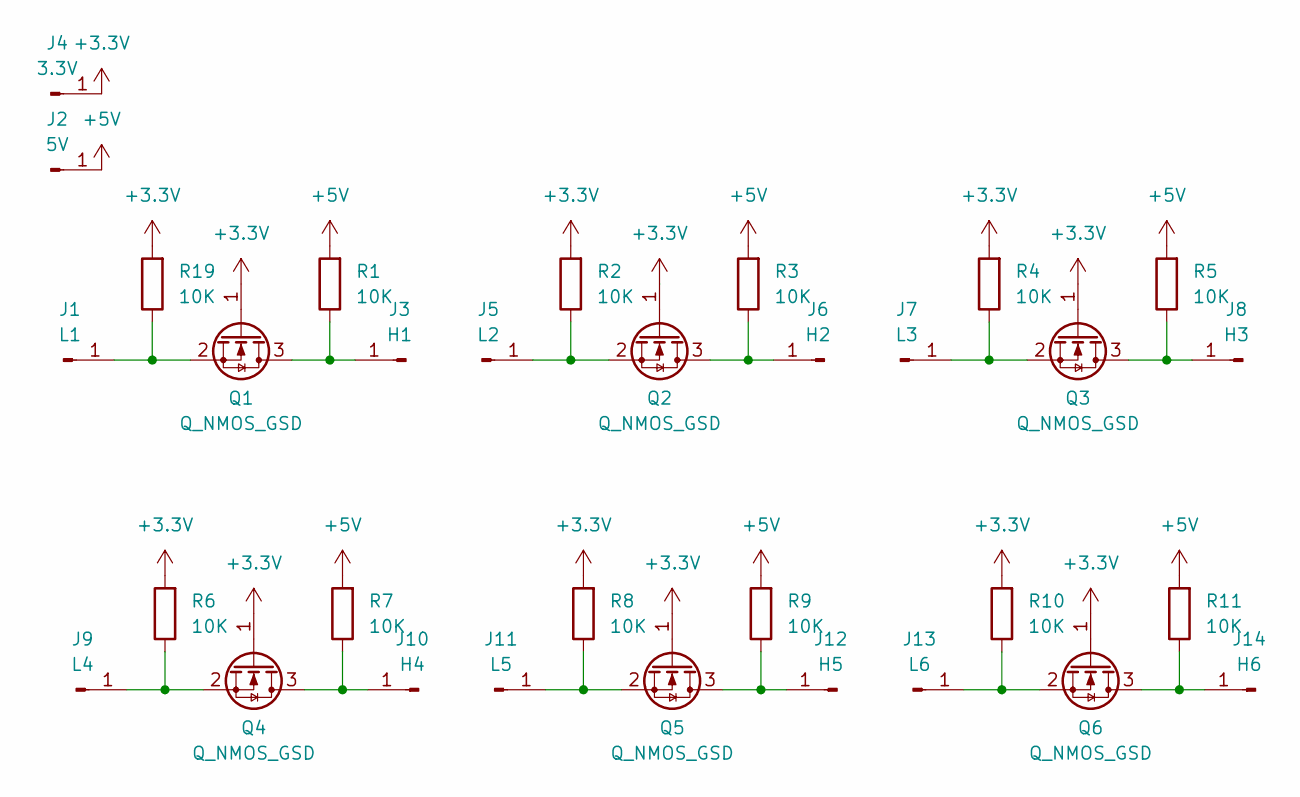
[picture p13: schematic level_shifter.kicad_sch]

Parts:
J1: L1; SolderWirePad_1x01_SMD_1x2mm
J2: 5V; SolderWirePad_1x01_SMD_1x2mm
J3: H1; SolderWirePad_1x01_SMD_1x2mm
J4: 3.3V; SolderWirePad_1x01_SMD_1x2mm
J5: L2; SolderWirePad_1x01_SMD_1x2mm
J6: H2; SolderWirePad_1x01_SMD_1x2mm
J7: L3; SolderWirePad_1x01_SMD_1x2mm
J8: H3; SolderWirePad_1x01_SMD_1x2mm
J9: L4; SolderWirePad_1x01_SMD_1x2mm
J10: H4; SolderWirePad_1x01_SMD_1x2mm
J11: L5; SolderWirePad_1x01_SMD_1x2mm
J12: H5; SolderWirePad_1x01_SMD_1x2mm
J13: L6; SolderWirePad_1x01_SMD_1x2mm
J14: H6; SolderWirePad_1x01_SMD_1x2mm
Q1, Q2, Q3, Q4, Q5, Q6: Q_NMOS_GSD; SOT-23_Handsoldering
R1, R2, R3, R4, R5, R6, R7, R8, R9, R10, R11, R19: 10K; R_0805_2012Metric

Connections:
+3.3V: J4.1, Q1.1 (G), Q2.1 (G), Q3.1 (G), Q4.1 (G), Q5.1 (G), Q6.1 (G), R2.2, R4.2, R6.2, R8.2, R10.2, R19.2
+5V: J2.1, R1.2, R3.2, R5.2, R7.2, R9.2, R11.2
unnamed: J1.1, Q1.2 (S), R19.1
unnamed: J3.1, Q1.3 (D), R1.1
unnamed: J5.1, Q2.2 (S), R2.1
unnamed: J6.1, Q2.3 (D), R3.1
unnamed: J7.1, Q3.2 (S), R4.1
unnamed: J8.1, Q3.3 (D), R5.1
unnamed: J9.1, Q4.2 (S), R6.1
unnamed: J10.1, Q4.3 (D), R7.1
unnamed: J11.1, Q5.2 (S), R8.1
unnamed: J12.1, Q5.3 (D), R9.1
unnamed: J13.1, Q6.2 (S), R10.1
unnamed: J14.1, Q6.3 (D), R11.1

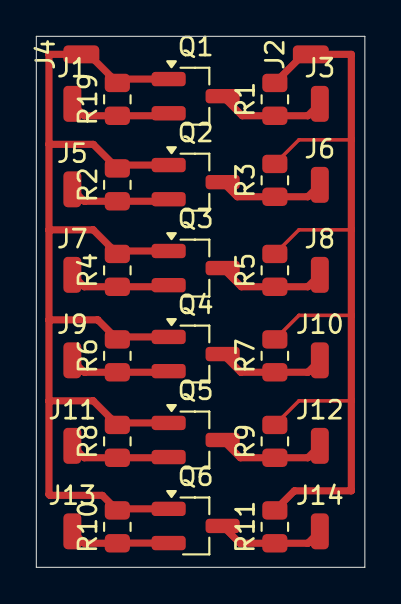
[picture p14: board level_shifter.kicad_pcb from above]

Board: 4 copper layers, 18.2 x 29.5 mm, 32 parts (0 on the bottom side), 14 nets.

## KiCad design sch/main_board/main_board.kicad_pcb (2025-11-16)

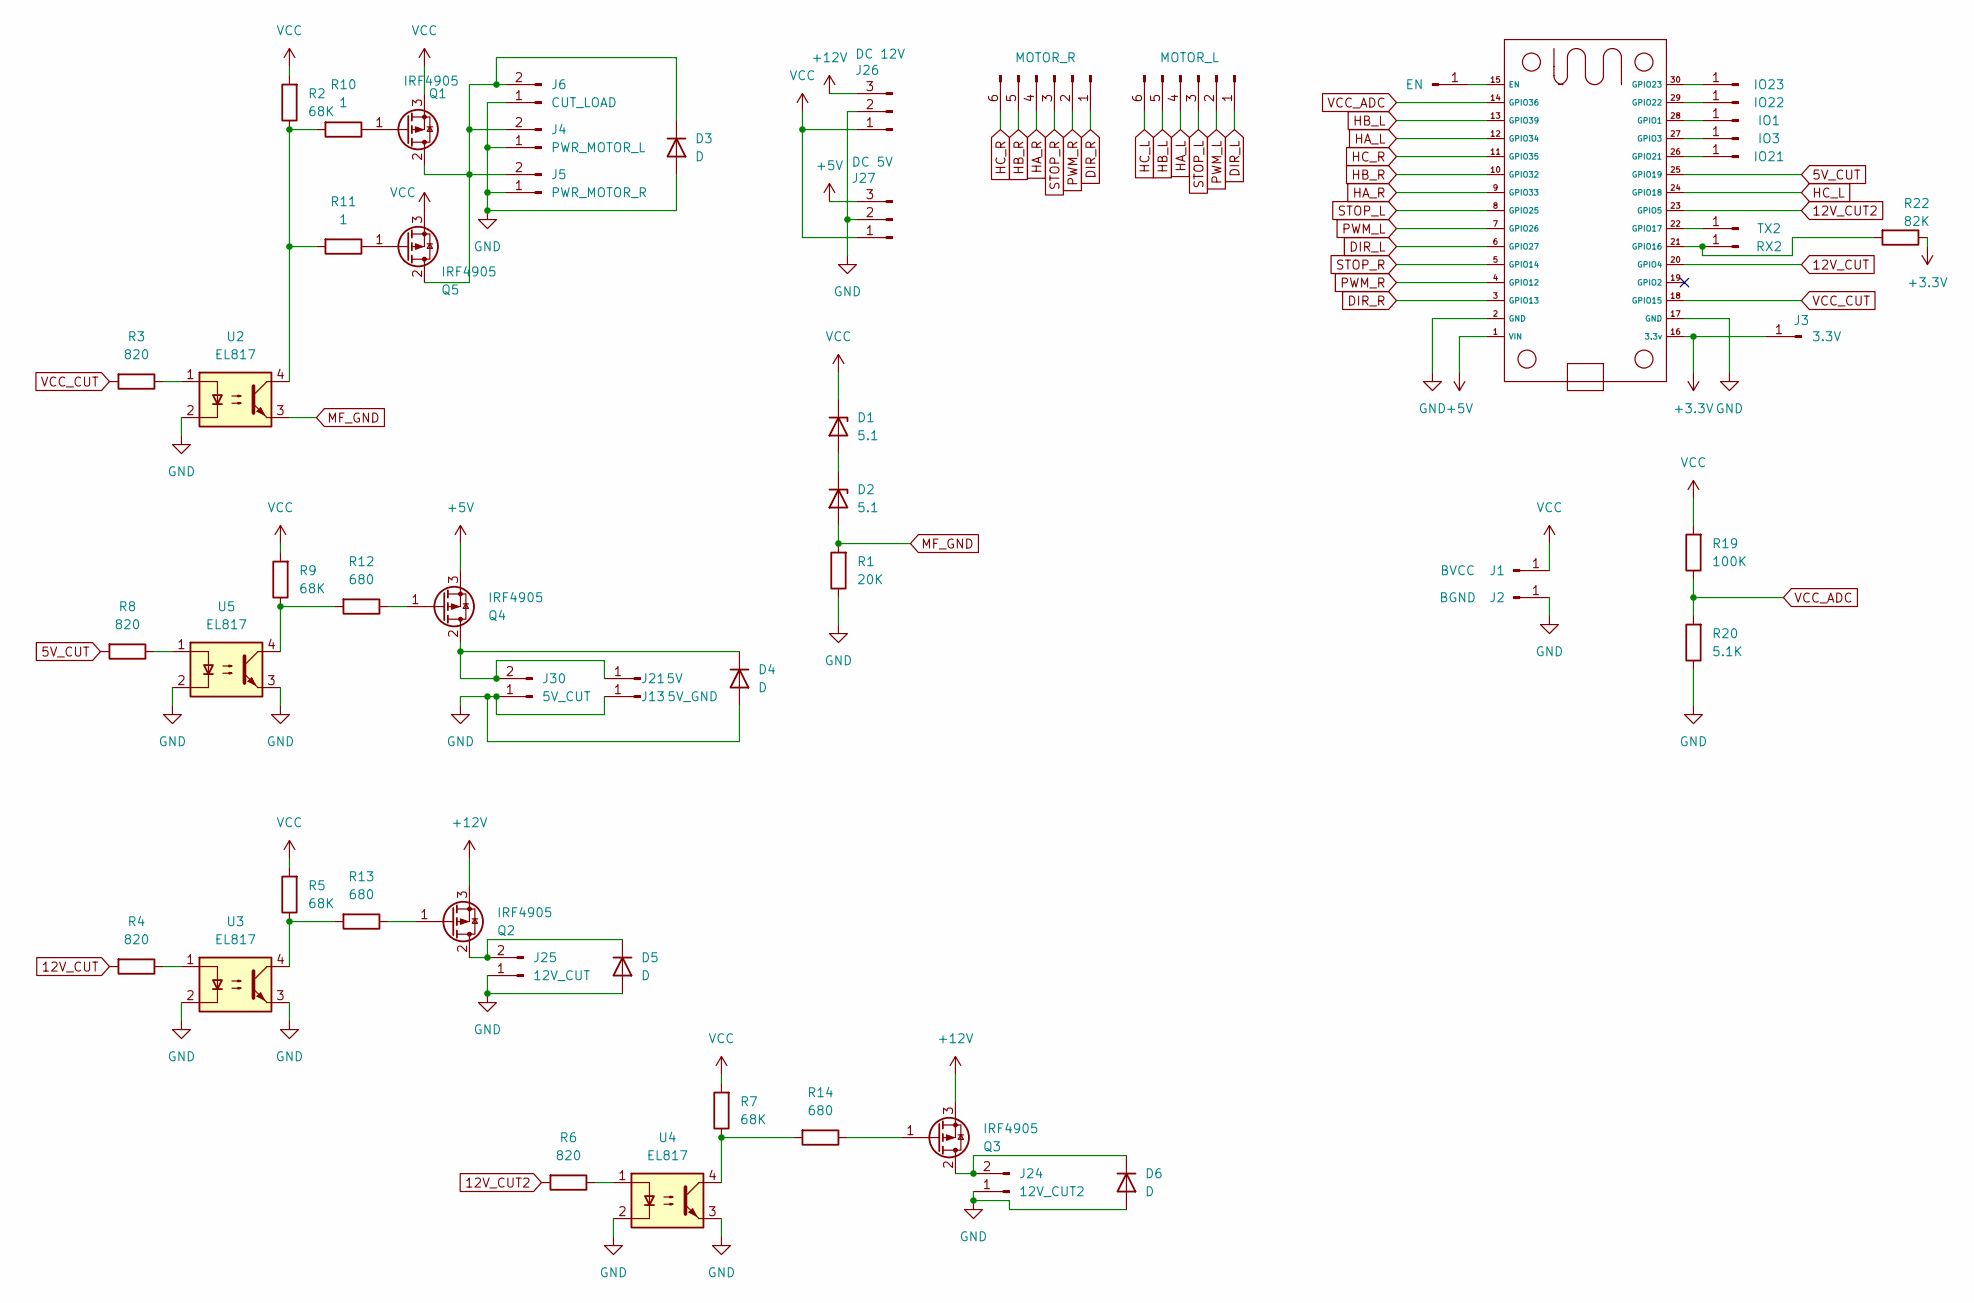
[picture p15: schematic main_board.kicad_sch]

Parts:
D1, D2: 5.1; D_5W_P12.70mm_Horizontal
D3, D4, D5, D6: D; D_2010_5025Metric_Pad1.52x2.65mm_HandSolder
J1: BVCC; SolderWirePad_1x01_SMD_4x8mm
J2: BGND; SolderWirePad_1x01_SMD_4x8mm
J3: 3.3V; SolderWirePad_1x01_SMD_2x4mm
J4: PWR_MOTOR_L; SolderWire-2.5sqmm_1x02_P7.2mm_D2.4mm_OD3.6mm
J5: PWR_MOTOR_R; SolderWire-2.5sqmm_1x02_P7.2mm_D2.4mm_OD3.6mm
J6: CUT_LOAD; SolderWire-2.5sqmm_1x02_P7.2mm_D2.4mm_OD3.6mm
J7: MOTOR_R; JST_XH_B6B-XH-A_1x06_P2.50mm_Vertical
J8: MOTOR_L; JST_XH_B6B-XH-A_1x06_P2.50mm_Vertical
J9: EN; SolderWirePad_1x01_SMD_1.5x3mm
J13: 5V_GND; SolderWirePad_1x01_SMD_2x4mm
J14: IO23; SolderWirePad_1x01_SMD_1.5x3mm
J15: IO22; SolderWirePad_1x01_SMD_1.5x3mm
J16: IO1; SolderWirePad_1x01_SMD_1.5x3mm
J17: IO3; SolderWirePad_1x01_SMD_1.5x3mm
J18: IO21; SolderWirePad_1x01_SMD_1.5x3mm
J21: 5V; SolderWirePad_1x01_SMD_2x4mm
J22: TX2; SolderWirePad_1x01_SMD_1.5x3mm
J23: RX2; SolderWirePad_1x01_SMD_1.5x3mm
J24: 12V_CUT2; SolderWire-1sqmm_1x02_P5.4mm_D1.4mm_OD2.7mm
J25: 12V_CUT; SolderWire-1sqmm_1x02_P5.4mm_D1.4mm_OD2.7mm
J26: DC 12V; SolderWire-1.5sqmm_1x03_P6mm_D1.7mm_OD3mm
J27: DC 5V; SolderWire-1.5sqmm_1x03_P6mm_D1.7mm_OD3mm
J30: 5V_CUT; SolderWire-1sqmm_1x02_P5.4mm_D1.4mm_OD2.7mm
Q1, Q2, Q3, Q4, Q5: IRF4905; TO-220-3_Vertical
R1: 20K; R_0805_2012Metric
R2, R5, R7, R9: 68K; R_0805_2012Metric
R3, R4, R6, R8: 820; R_0805_2012Metric
R10, R11: 1; R_0805_2012Metric
R12, R13, R14: 680; R_0805_2012Metric
R19: 100K; R_0805_2012Metric
R20: 5.1K; R_0805_2012Metric
R22: 82K; R_0805_2012Metric
U1: ESP32_30pin
U2, U3, U4, U5: EL817; SMDIP-4_W9.53mm

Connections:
5V_CUT: R8.2, U1.25 (GPIO19)
12V_CUT: R4.2, U1.20 (GPIO4)
12V_CUT2: R6.2, U1.23 (GPIO5)
+3.3V: J3.1, R22.1, U1.16 (3.3v)
+5V: J27.3, Q4.3 (S), U1.1 (VIN)
+12V: J26.3, Q2.3 (S), Q3.3 (S)
DIR_L: J8.1, U1.6 (GPIO27)
DIR_R: J7.1, U1.3 (GPIO13)
GND: D3.2 (A), D4.2 (A), D5.2 (A), D6.2 (A), J2.1, J4.1, J5.1, J6.1, J13.1, J24.1, J25.1, J26.2, J27.2, J30.1, R1.1, R20.1, U1.2 (GND), U1.17 (GND), U2.2, U3.2, U3.3, U4.2, U4.3, U5.2, U5.3
HA_L: J8.4, U1.12 (GPIO34)
HA_R: J7.4, U1.9 (GPIO33)
HB_L: J8.5, U1.13 (GPIO39)
HB_R: J7.5, U1.10 (GPIO32)
HC_L: J8.6, U1.24 (GPIO18)
HC_R: J7.6, U1.11 (GPIO35)
MF_GND: D2.2 (A), R1.2, U2.3
unnamed: D1.2 (A), D2.1 (K)
unnamed: D3.1 (K), J4.2, J5.2, J6.2, Q1.2 (D), Q5.2 (D)
unnamed: D4.1 (K), J21.1, J30.2, Q4.2 (D)
unnamed: D5.1 (K), J25.2, Q2.2 (D)
unnamed: D6.1 (K), J24.2, Q3.2 (D)
unnamed: J9.1, U1.15 (EN)
unnamed: J14.1, U1.30 (GPIO23)
unnamed: J15.1, U1.29 (GPIO22)
unnamed: J16.1, U1.28 (GPIO1)
unnamed: J17.1, U1.27 (GPIO3)
unnamed: J18.1, U1.26 (GPIO21)
unnamed: J22.1, U1.22 (GPIO17)
unnamed: J23.1, R22.2, U1.21 (GPIO16)
unnamed: Q1.1 (G), R10.1
unnamed: Q2.1 (G), R13.1
unnamed: Q3.1 (G), R14.1
unnamed: Q4.1 (G), R12.1
unnamed: Q5.1 (G), R11.1
unnamed: R3.1, U2.1
unnamed: R4.1, U3.1
unnamed: R6.1, U4.1
unnamed: R8.1, U5.1
unnamed: R2.1, R10.2, R11.2, U2.4
unnamed: R9.1, R12.2, U5.4
unnamed: R5.1, R13.2, U3.4
unnamed: R7.1, R14.2, U4.4
PWM_L: J8.2, U1.7 (GPIO26)
PWM_R: J7.2, U1.4 (GPIO12)
STOP_L: J8.3, U1.8 (GPIO25)
STOP_R: J7.3, U1.5 (GPIO14)
VCC: D1.1 (K), J1.1, J26.1, J27.1, Q1.3 (S), Q5.3 (S), R2.2, R5.2, R7.2, R9.2, R19.2
VCC_ADC: R19.1, R20.2, U1.14 (GPIO36)
VCC_CUT: R3.2, U1.18 (GPIO15)

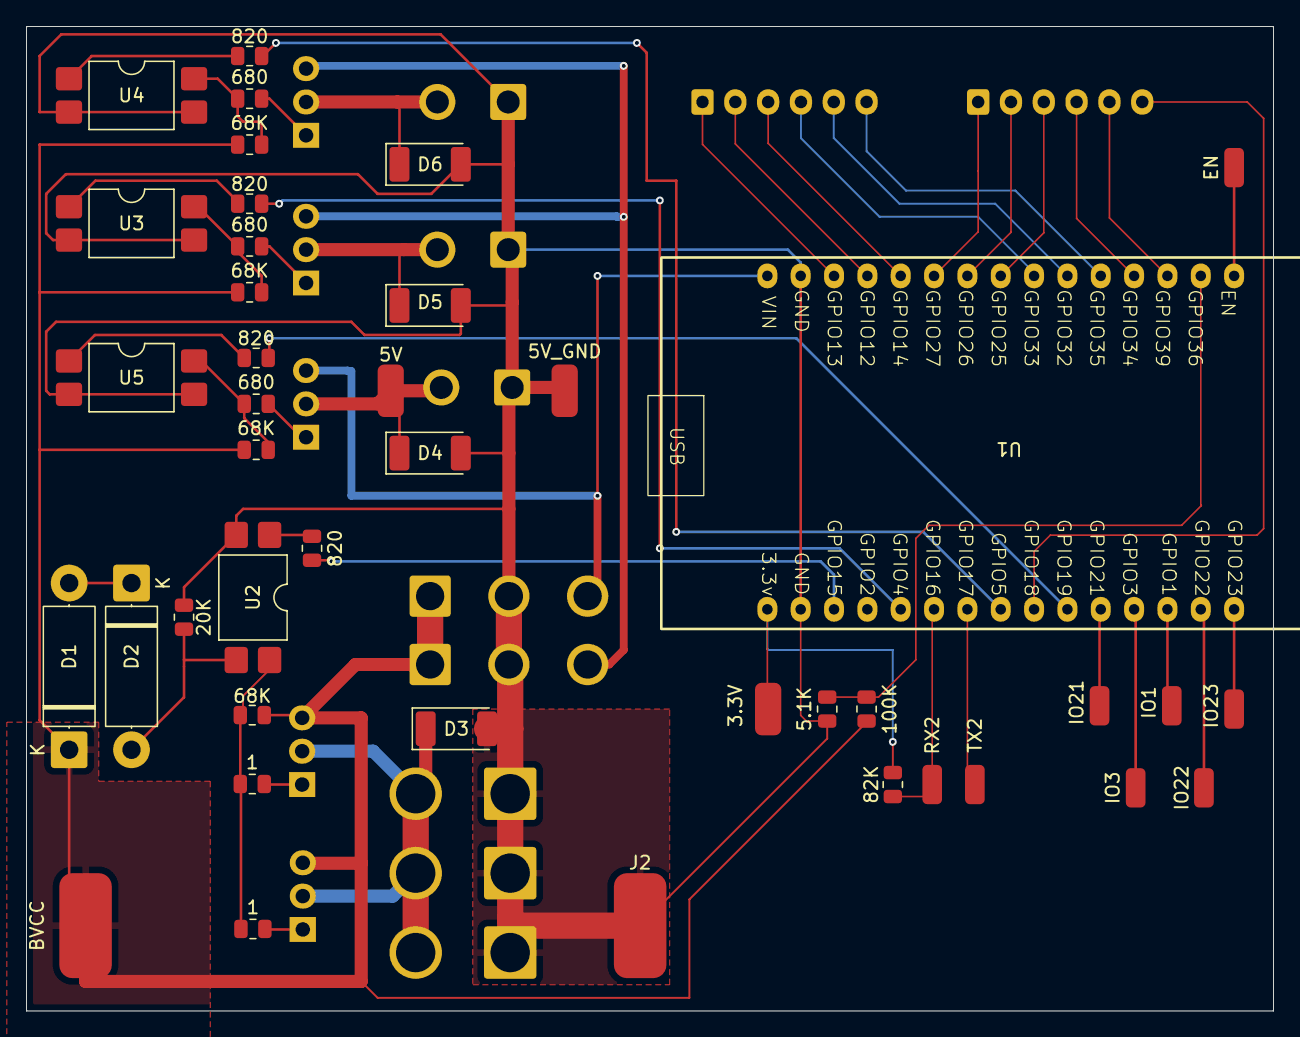
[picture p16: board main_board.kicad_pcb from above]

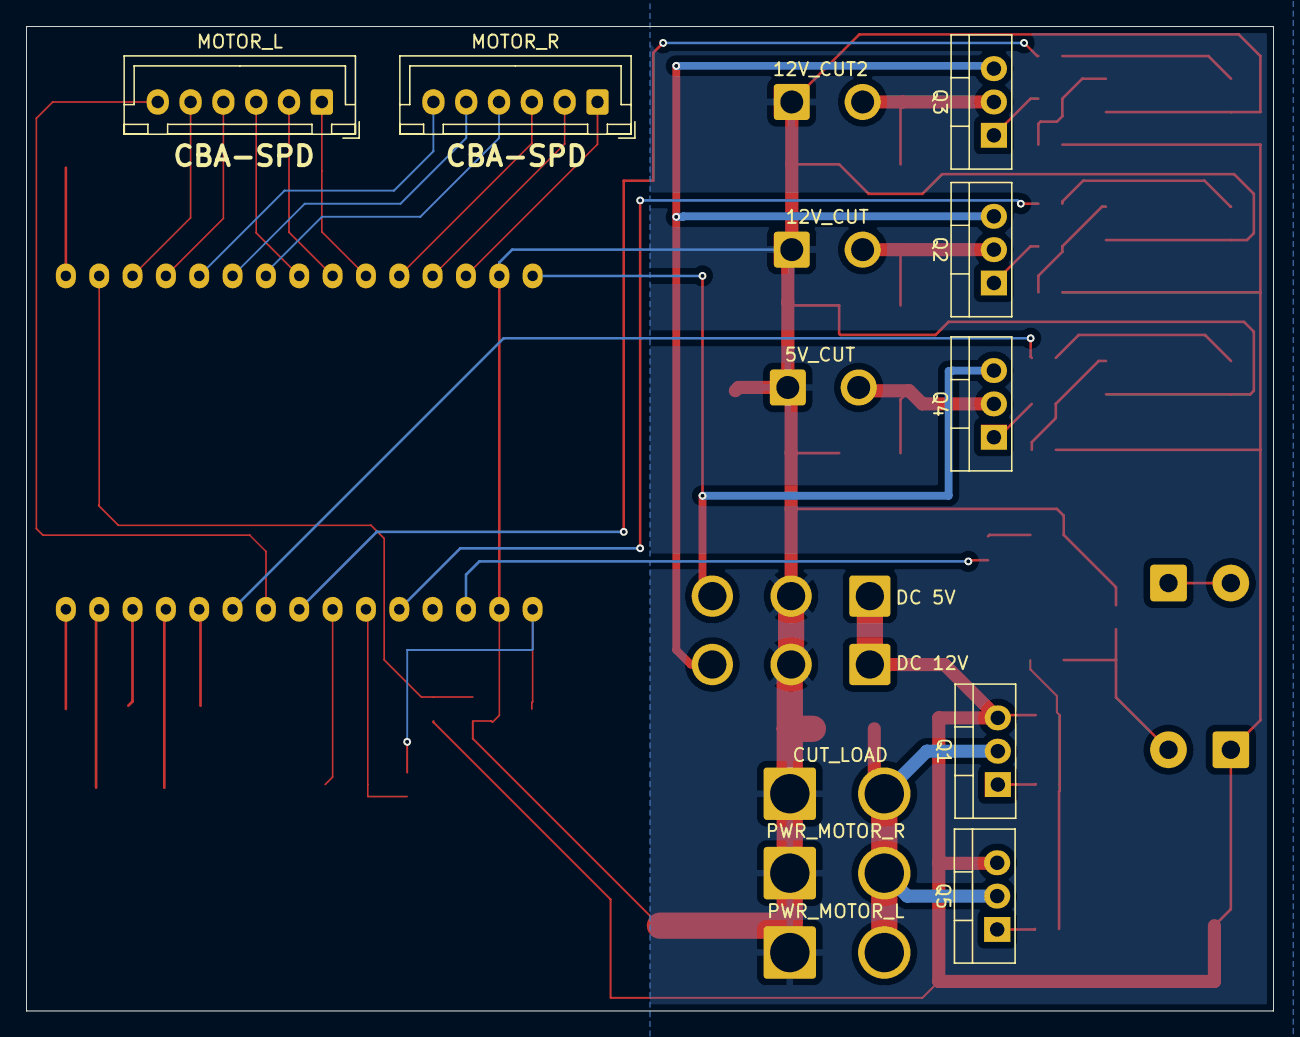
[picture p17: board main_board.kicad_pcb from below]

Board: 2 copper layers, 95.0 x 75.0 mm, 56 parts (15 on the bottom side), 49 nets.

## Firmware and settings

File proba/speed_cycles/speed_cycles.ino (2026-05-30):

#include <Arduino.h>

constexpr int VCC_CUT_PIN = 15;
constexpr int V5_CUT_PIN = 19;
constexpr int V12_CUT_PIN = 4;
constexpr int V12_CUT2_PIN = 5;

constexpr int ML_PWM_PIN = 26;
constexpr int ML_DIR_PIN = 27;
constexpr int ML_STOP_PIN = 25;
constexpr int ML_A = 34;
constexpr int ML_B = 23;
constexpr int ML_C = 18;

constexpr int MR_PWM_PIN = 12;
constexpr int MR_DIR_PIN = 13;
constexpr int MR_STOP_PIN = 14;
constexpr int MR_A = 33;
constexpr int MR_B = 32;
constexpr int MR_C = 35;

constexpr int VCC_ADC_PIN = 36;


volatile uint32_t speed_cycles[4]={};
volatile int speed_directions[3]={};

uint32_t m_cycles_diff = 0;
int m_directions = 0;

int32_t printed_cycle = 0;

float cpu_freq = 0.0;
uint32_t pwm_duty = 0;
constexpr int pwm_bits=10;

constexpr float WHEEL_PULSES_PER_ROTATION=90.0;
constexpr float WHEEL_DIAMETER=6.5*0.0254; //meters
constexpr float WHEEL_PERIMETER=M_PI*WHEEL_DIAMETER;
constexpr float WHEEL_PULSES_PER_METER=WHEEL_PULSES_PER_ROTATION/WHEEL_PERIMETER;

static constexpr int hall2idx[]={-1,4,2,3,0,5,1,-1};
int m_hall_idx = 0;

constexpr unsigned TIMER_MS=10;
static constexpr unsigned PERIODS_COUNT = 50;
static constexpr float KPER_SEC=1000.0/(PERIODS_COUNT*TIMER_MS);

unsigned m_timer_val=0;
int m_periods[PERIODS_COUNT];
int m_speed_ticks_count = 0;

int last_increase = 0;

double cpu_speed_sum = 0.0;
double timer_speed_sum = 0.0;
unsigned measures_count=0;

void enablePowerModules(bool power_on)
{
  int val = power_on? HIGH: LOW;
  digitalWrite(VCC_CUT_PIN, val);
  //digitalWrite(V5_CUT_PIN, val);
  //digitalWrite(V12_CUT_PIN, val);
  //digitalWrite(V12_CUT2_PIN, val);
}

void setupPowerPins()
{
  enablePowerModules(false);
  
  pinMode(VCC_CUT_PIN, OUTPUT);
  pinMode(V5_CUT_PIN, OUTPUT);
  pinMode(V12_CUT_PIN, OUTPUT);
  pinMode(V12_CUT2_PIN, OUTPUT);
}

void allOtherPinsToInputState()
{
  pinMode(ML_PWM_PIN, INPUT);
  pinMode(ML_DIR_PIN, INPUT);
  pinMode(ML_STOP_PIN, INPUT);
  pinMode(ML_A, INPUT);
  pinMode(ML_B, INPUT);
  pinMode(ML_C, INPUT);

  pinMode(MR_PWM_PIN, INPUT);
  pinMode(MR_DIR_PIN, INPUT);
  pinMode(MR_STOP_PIN, INPUT);
  pinMode(MR_A, INPUT);
  pinMode(MR_B, INPUT);
  pinMode(MR_C, INPUT);

  pinMode(VCC_ADC_PIN, INPUT);
}

void runLeftMotor()
{
  pinMode(ML_STOP_PIN, OUTPUT);
  pinMode(ML_DIR_PIN, OUTPUT);
  pinMode(ML_PWM_PIN, OUTPUT);

  ledcSetup(0, 20000, pwm_bits);
  digitalWrite(ML_STOP_PIN, LOW);
  digitalWrite(ML_DIR_PIN, HIGH);
  ledcAttachPin(ML_PWM_PIN, 0);
  
  ledcWrite(0, pwm_duty);
}

int readHallIndex()
{
  unsigned st = (digitalRead(ML_A) == HIGH) | ((digitalRead(ML_B) == HIGH)<<1) | ((digitalRead(ML_C) == HIGH)<<2);
  return hall2idx[st];
}

void IRAM_ATTR left_tick_isr()
{
  uint32_t cur_cycle = ESP.getCycleCount();

  int hall_idx = readHallIndex();

  //Incorrect state of hall sensors
  if(hall_idx == -1)
    return;

  int d = hall_idx - m_hall_idx;
  if(std::abs(d)>3)
    d += 6*(d<0) -6*(d>0);

  m_hall_idx = hall_idx;

  unsigned t = m_timer_val;
  m_periods[t%PERIODS_COUNT] += d;
  m_speed_ticks_count += d;

  m_directions -= speed_directions[0];

  speed_directions[0]=speed_directions[1];
  speed_directions[1]=speed_directions[2];
  speed_directions[2]=d;

  m_directions += d;

  speed_cycles[0]=speed_cycles[1];
  speed_cycles[1]=speed_cycles[2];
  speed_cycles[2]=speed_cycles[3];
  speed_cycles[3] = cur_cycle;

  uint32_t diff = speed_cycles[1] - speed_cycles[0];
  diff += speed_cycles[2] - speed_cycles[1];
  diff += cur_cycle - speed_cycles[2];

  m_cycles_diff = diff;
}

void IRAM_ATTR right_tick_isr()
{
//  ++ticks_count;
}

void IRAM_ATTR SpeedTimer_ISR()
{
  unsigned timer_val = m_timer_val + 1;

  unsigned new_pi=timer_val%PERIODS_COUNT;
  unsigned old_pi=m_timer_val%PERIODS_COUNT;

  if(new_pi != old_pi)
  {
    m_speed_ticks_count-=m_periods[new_pi];
    m_periods[new_pi] = 0;
  }

  m_timer_val = timer_val;
}

void setup() {
  allOtherPinsToInputState();
  // initialize serial communication at 115200 bits per second:
  Serial.begin(115200);

  cpu_freq = ESP.getCpuFreqMHz()*1000000.0;

  setupPowerPins();
  
  enablePowerModules(true);

  m_hall_idx = readHallIndex();
  
  hw_timer_t *speed_timer = timerBegin(0, 80, true);
  timerAttachInterrupt(speed_timer, &SpeedTimer_ISR, true);
  timerAlarmWrite(speed_timer, TIMER_MS*1000, true);
  timerAlarmEnable(speed_timer);

  attachInterrupt(digitalPinToInterrupt(ML_A), left_tick_isr, CHANGE);
  attachInterrupt(digitalPinToInterrupt(ML_B), left_tick_isr, CHANGE);
  attachInterrupt(digitalPinToInterrupt(ML_C), left_tick_isr, CHANGE);

  //attachInterrupt(digitalPinToInterrupt(MR_A), right_tick_isr, CHANGE);
  //attachInterrupt(digitalPinToInterrupt(MR_B), right_tick_isr, CHANGE);
  //attachInterrupt(digitalPinToInterrupt(MR_C), right_tick_isr, CHANGE);

  runLeftMotor();
}

float get_speed_by_timer()
{
  return m_speed_ticks_count*KPER_SEC/WHEEL_PULSES_PER_METER;
}

float get_speed_by_cpu()
{
  uint32_t diff = m_cycles_diff;
  int d = m_directions;

  return cpu_freq*d/WHEEL_PULSES_PER_METER/diff;
}

float get_immediate_speed_by_cpu()
{
  uint32_t diff = speed_cycles[3]-speed_cycles[2];
  int d = speed_directions[2];

  return cpu_freq*d/WHEEL_PULSES_PER_METER/diff;
}

void print_speed()
{
  if(printed_cycle == speed_cycles[3])
    return;
  printed_cycle = speed_cycles[3];

  float timer_speed = get_speed_by_timer();

  float im_speed = get_immediate_speed_by_cpu();
  float cpu_speed = get_speed_by_cpu();
  cpu_speed_sum += cpu_speed;
  timer_speed_sum += timer_speed;
  ++measures_count;

  double avg_cpu_speed = cpu_speed_sum / measures_count;
  double avg_timer_speed = timer_speed_sum / measures_count;

  //Serial.printf("pwm_duty=%u speed=%f(%f)(%lf) timer_speed=%f(%lf) \n",pwm_duty, im_speed, cpu_speed,avg_cpu_speed, timer_speed,avg_timer_speed);
}

void increase_pwm()
{
  int ms = millis();
  if(ms-last_increase<5000)
    return;
  
  last_increase = ms;

  double avg_cpu_speed = cpu_speed_sum / measures_count;
  double avg_timer_speed = timer_speed_sum / measures_count;

  cpu_speed_sum = 0.0;
  timer_speed_sum = 0.0;
  measures_count=0;
  
  pwm_duty += 1;
  pwm_duty %= (1<<pwm_bits);

  uint32_t diff = ESP.getCycleCount() - speed_cycles[3];
  bool do_reset = diff*1.0>cpu_freq;

  if(do_reset)
  {
    Serial.printf("increase_pwm(): reset\n");
    digitalWrite(ML_STOP_PIN, HIGH);
    delay(110);
  }
  
  ledcWrite(0, pwm_duty);
  Serial.printf("increase_pwm(): prev:(cpu_speed=%lf timer_speed=%lf) pwm_duty=%u diff=%u do_reset=%d\n", avg_cpu_speed,avg_timer_speed, pwm_duty, diff, do_reset);

  if(do_reset)
    digitalWrite(ML_STOP_PIN, LOW);
}

void loop()
{
  print_speed();
  increase_pwm();
}

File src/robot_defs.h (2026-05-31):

#pragma once
#include <math.h>

constexpr int FAIL_SAFE_DELAY = 750;

constexpr float WHEEL_PULSES_PER_ROTATION=90.0;
constexpr float WHEEL_DIAMETER=6.5*0.0254; //meters
constexpr float WHEEL_PERIMETER=M_PI*WHEEL_DIAMETER;
constexpr float WHEEL_PULSES_PER_METER=WHEEL_PULSES_PER_ROTATION/WHEEL_PERIMETER;
 
constexpr float MAX_SPEED = 4.0; //Estimated speed of unloaded wheel on maximum power (meters per second)
constexpr float OFF_SPEED = 0.01; //meters per second
constexpr float CLOSE_TO_ZERO_ACCELERATION = 0.02;
constexpr float CLOSE_TO_ZERO_SPEED_DIFF = 0.05;
constexpr float UP_SPEED_CORRECTION = 0.01;
constexpr float DOWN_SPEED_CORRECTION = 0.01;
constexpr float BREAK_MAX_SPEED_DIFF = 1.0;
constexpr float BREAK_MAX_SPEED_DIFF_WITH_ACCELERATION = 0.5;
constexpr float KICK_PWM_CORRECTION = 0.02;
constexpr float BREAK_PWM_CORRECTION = 0.02;
constexpr unsigned long MAIN_CYCLE_DELAY = 10;
constexpr float EXPECTED_PWM_DELAY = MAIN_CYCLE_DELAY/1000.0;
constexpr float DEFAULT_PWM_LIMIT = 0.1;

constexpr float RELATIVE_MAX_SPEED = 0.3; //meters per second
constexpr float RELATIVE_MAX_ROT = 0.2; //meters per second

constexpr unsigned SPEED_TIMEOUT_MS=500;

constexpr unsigned STALED_TRIGER_MS=300;
constexpr unsigned STALED_DURATION_MS=120;

constexpr float POWER_OFF_VOLTAGE = 21.0; //Volts
constexpr float POWER_ON_VOLTAGE = 22.0; //Volts
constexpr unsigned long DEEP_SLEEP_DURATION = 5*60; //Seconds
constexpr unsigned long LOW_VOLTAGE_SLEEP_DELAY = 5000; //Milliseconds. Delay before go sleep on low voltage
constexpr float VCC_REF_ADC1=1333.0; //Reference ADC value point 1
constexpr float VCC_REF_V1=25.0; //Reference voltage point 1
constexpr float VCC_REF_ADC2=739.0; //Reference ADC value point 2
constexpr float VCC_REF_V2=15.0; //Reference voltage point 1

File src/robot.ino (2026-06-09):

//Board ESP32-WROOM-DA Module
#include "motor_speed.h"
#include "robot_pins.h"
#include "power_managment.h"
#include <BluetoothSerial.h>
#include <esp_now.h>
#include <WiFi.h>
#include <StreamString.h>

#define DEVICE_NAME "rccar"
static const int portNumber = 1500;

const char *bluetooth_pin = "1234";

MotorZsx11h leftMotor(ML_PWM_PIN, ML_DIR_PIN, 0, ML_STOP_PIN, true, ML_A,ML_B,ML_C);
MotorZsx11h rightMotor(MR_PWM_PIN, MR_DIR_PIN, 1, MR_STOP_PIN, false, MR_A,MR_B,MR_C);

MotorSpeed leftWheel(leftMotor);
MotorSpeed rightWheel(rightMotor);

volatile unsigned long last_ms = 0;
bool auto_cmd_blocked = false;
static volatile TaskHandle_t motor_task_handle = NULL;
uint8_t sbuf[256];

template<typename T>
void processCommand(T& stream, const char* buf,bool blocked);

static void motors_task(void *);

void OnEspNowDataRecv(const uint8_t * mac, const uint8_t *incomingData, int len);

BluetoothSerial SerialBT;
#define SerialAuto Serial2

esp_now_peer_info_t remoteEspNowPeer;
uint8_t remoteEspNowMac[] = {
#include "esp_now_remote_mac.h"  
};
uint8_t esp_now_buf[250];
uint8_t esp_now_local_buf[251];
bool esp_now_buf_available = false;

float relative_max_speed = RELATIVE_MAX_SPEED;

struct DriveRequest
{
  bool active = false;
  float speed_ms = 0.0;
  float rel_rotation = 0.0;
  float distance = 0.0;
  bool use_distance = false;
};

DriveRequest drive_request;


void IRAM_ATTR left_tick_isr()
{
  leftWheel.speed_pin_isr();
}

void IRAM_ATTR right_tick_isr()
{
  rightWheel.speed_pin_isr();
}

void setup() 
{
  allOtherPinsToInputState();

  Serial.begin(115200);

  setupPowerPins();
  setupVCC_ADC();
  checkIfEnoughVoltageToStart();
  enablePowerModules(true);

  delay(100);

  SerialAuto.begin(115200);

  SerialBT.begin(DEVICE_NAME); //Bluetooth device name
  SerialBT.setPin(bluetooth_pin);

  WiFi.mode(WIFI_STA);
  if (esp_now_init() != ESP_OK)
    Serial.println("esp_now_init() failed");

  esp_now_local_buf[250]=0;
  
  memcpy(remoteEspNowPeer.peer_addr, remoteEspNowMac, sizeof(remoteEspNowMac));
  remoteEspNowPeer.channel = 0;  
  remoteEspNowPeer.encrypt = false;
  
  if (esp_now_add_peer(&remoteEspNowPeer) != ESP_OK)
    Serial.println("esp_now_add_peer() failed");

  esp_now_register_recv_cb(OnEspNowDataRecv);

  leftWheel.init();
  rightWheel.init();

  attachInterrupt(digitalPinToInterrupt(ML_A), left_tick_isr, CHANGE);
  attachInterrupt(digitalPinToInterrupt(ML_B), left_tick_isr, CHANGE);
  attachInterrupt(digitalPinToInterrupt(ML_C), left_tick_isr, CHANGE);

  attachInterrupt(digitalPinToInterrupt(MR_A), right_tick_isr, CHANGE);
  attachInterrupt(digitalPinToInterrupt(MR_B), right_tick_isr, CHANGE);
  attachInterrupt(digitalPinToInterrupt(MR_C), right_tick_isr, CHANGE);

  xTaskCreateUniversal(motors_task, "motors", 4096, NULL, 1, (TaskHandle_t*)&motor_task_handle, CONFIG_ARDUINO_UDP_RUNNING_CORE);
}

template<typename T>
void processStream(T& stream, const char* caption,bool blocked)
{
  if (!stream.available())
    return;


  unsigned long timeout = millis() + 1000;

  for(int i = 0 ; timeout>millis();)
  {
    int len = stream.available();
    
    if(len == 0)
    {
      delay(100);
      continue;
    }
    
    if(i + len>sizeof(sbuf)-1)
      len = sizeof(sbuf)-1 - i;
    
    stream.readBytes(sbuf + i, len);
    
    sbuf[i+len] = 0;
    i+=len;

    if(strchr((const char*)sbuf,'\r') != nullptr)
      break;
  }

  // if(!blocked)
  // {
  //   Serial.print(caption);
  //   Serial.print(": ");
  //   Serial.println((const char*)sbuf);
  // }

  char* cur = (char*)sbuf;
  for(char* next = strchr(cur, '\r'); next!=nullptr;)
  {
    *next = 0;
    processCommand(stream, cur, blocked);

    cur=next+1;
    next= strchr(cur, '\r');
  }
}

void OnEspNowDataRecv(const uint8_t * mac, const uint8_t *incomingData, int len)
{
  if(memcmp(mac,remoteEspNowMac,sizeof(remoteEspNowMac))!=0)
    return;
  
  memcpy(esp_now_buf,incomingData,len);
  esp_now_buf_available = true;
}

void processEsp()
{
  if(!esp_now_buf_available)
    return;
  
  memcpy(esp_now_local_buf,esp_now_buf,sizeof(esp_now_buf));
  esp_now_buf_available = false;

  StreamString answer;
  processCommand(answer, (const char*)esp_now_local_buf, false);
  esp_now_send(remoteEspNowMac, (uint8_t *) answer.c_str(), answer.length());
}

bool processDriveCommand(const char* buf)
{
  if(buf[0] == 0)
    return false;

  float rel_speed=atof(buf);
  rel_speed=constrain(rel_speed, -1.0, 1.0);

  const char* cdiv = strstr (buf,";");
  if(!cdiv)
    return false;
  
  float rel_rotation=atof(cdiv + 1);
  rel_rotation=constrain(rel_rotation, -1.0, 1.0);

  drive_request = DriveRequest();
  drive_request.active=true;
  drive_request.speed_ms = rel_speed * relative_max_speed;
  drive_request.rel_rotation = rel_rotation;

  last_ms = millis();

  return true;
}

bool processDistanceCommand(const char* buf)
{
  if(buf[0] == 0)
    return false;

  float rel_speed=atof(buf);
  rel_speed=constrain(rel_speed, -1.0, 1.0);

  const char* cdiv = strstr (buf,";");
  if(!cdiv)
    return false;
  
  float rel_rotation=atof(cdiv + 1);
  rel_rotation=constrain(rel_rotation, -1.0, 1.0);

  cdiv = strstr (cdiv + 1,";");
  if(!cdiv)
    return false;

  float distance=atof(cdiv + 1);
  if(distance<0)
    return false;

  drive_request = DriveRequest();
  drive_request.active=true;
  drive_request.speed_ms = rel_speed * relative_max_speed;
  drive_request.rel_rotation = rel_rotation;
  drive_request.distance = distance;
  drive_request.use_distance = true;

  last_ms = millis();

  return true;
}

bool processBlockCommand(const char* buf)
{
  if(buf[0] == 0)
    return false;

    auto_cmd_blocked=atol(buf)!=0;

  return true;
}

bool processRelMaxSpeedCommand(const char* buf)
{
  if(buf[0] == 0)
    return false;

  float speed = atof(buf);
  if(speed<=0.0 || speed>MAX_SPEED)
    return false;
  
  relative_max_speed = speed;

  return true;
}

bool processStateCommand(const char* buf, String& answer_params)
{
  float v = getVCCVoltage();
  float l = leftMotor.get_speed_meters();
  float r = rightMotor.get_speed_meters();
  answer_params =":"+String(v)+";"+String(l)+";"+String(r)+";"+String((int)auto_cmd_blocked);

  double cur_dist = 0.0;
  bool distance_mode = leftWheel.get_path(cur_dist);

  answer_params += ";";
  if(distance_mode)
    answer_params += String(cur_dist);

  distance_mode = rightWheel.get_path(cur_dist);

  answer_params += ";";
  if(distance_mode)
    answer_params += String(cur_dist);
  
  return true;
}

bool processSleepCommand(const char* buf)
{
  if(buf[0] == 0)
    return false;

  int seconds = atoi(buf);
  if(seconds<=0.0)
    return false;
  
  leftWheel.set_speed(0);
  rightWheel.set_speed(0);
  leftMotor.brake();
  rightMotor.brake();
  allOtherPinsToInputState();
  delay(2000);
  
  goToSleepMode(seconds);

  return true;
}
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

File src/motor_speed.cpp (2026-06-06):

#include <Arduino.h>
#include "motor_speed.h"

float MotorSpeed::m_pwm_limit = DEFAULT_PWM_LIMIT;

void MotorSpeed::apply()
{
  float cur_speed = m_motor.get_speed_meters();

  if(m_dst_speed==0.0 && std::abs(cur_speed)<=CLOSE_TO_ZERO_SPEED_DIFF)
  {
    m_motor.brake();
    reset_pid();
    return;
  }

  bool is_brake = false;
  float ctl_pwm=calc_pwm(cur_speed,is_brake);
  if(is_brake && m_motor.get_state() != Motor::st_brake)
  {
    m_motor.brake();
    return;
  }

  if(anti_stall())
    return;
  
  int pwm = ctl_pwm*Motor::MAX_PWM;
  pwm = constrain(pwm, -Motor::MAX_PWM, Motor::MAX_PWM);

  if(std::abs(pwm)<Motor::MIN_PWM)
    m_motor.soft_stop();
  else if(pwm<0)
    m_motor.backward(-pwm);
  else
    m_motor.forward(pwm);
}

float MotorSpeed::calc_pwm(float cur_speed, bool &is_brake)
{
  unsigned long cur_time = millis();
  const shot_t& prev = m_shots[m_cur_shot];
  const shot_t& pprev = m_shots[wrap_shot_idx(m_cur_shot-1)];

  if(prev.is_stalled && cur_speed == 0.0 && cur_time-prev.time < STALED_DURATION_MS)
  {
    //Serial.printf("stall cool down: diff=%u\n", cur_time - prev.time);
    is_brake = prev.is_brake;
    return prev.pwm();
  }

  if(prev.dst_speed == m_dst_speed && prev.speed == cur_speed)
  {
    float blind_ms = m_motor.get_blind_ms(m_dst_speed);
    if(blind_ms > cur_time - prev.time)
    {
      //Serial.printf("skip: blind_ms=%.4f diff=%u\n",blind_ms, cur_time - prev.time);
      is_brake = prev.is_brake;
      return prev.pwm();
    }
  }

  m_cur_shot = wrap_shot_idx(m_cur_shot + 1);
  shot_t& cur = m_shots[m_cur_shot];

  cur = shot_t();
  cur.time = cur_time;
  cur.speed = cur_speed;
  cur.dst_speed = m_dst_speed;


  float cur_delay;
  if(cur.time == prev.time)
    cur_delay=EXPECTED_PWM_DELAY;
  else
    cur_delay = (cur.time - prev.time)/1000.0;

  float cur_acc = (cur_speed-prev.speed)/cur_delay;
  const float kdirection = (m_dst_speed<0)? -1.0:1.0;
  const float kincrease = (cur_speed*kdirection<=m_dst_speed*kdirection)? 1.0:-1.0;
  const float kspeed_correction = kincrease>0? UP_SPEED_CORRECTION:DOWN_SPEED_CORRECTION;

  cur.func_pwm = speed2pwm(m_dst_speed);
  cur.correction_pwm = prev.correction_pwm;

  if(cur_acc*kincrease*kdirection<0.0 || cur_acc*kincrease*kdirection<CLOSE_TO_ZERO_ACCELERATION)
  {
    cur.correction_pwm = prev.correction_pwm+(m_dst_speed-cur_speed)*kspeed_correction;
    //Serial.printf("%f=%f+(%f-%f)*%f\n",cur.correction_pwm, prev.correction_pwm, m_dst_speed, cur_speed, kspeed_correction);
  }

  if(kincrease>0)
  {
    if(pprev.speed == 0.0 && prev.speed ==0.0 && cur_speed == 0.0 && std::abs(m_dst_speed)>CLOSE_TO_ZERO_SPEED_DIFF)
        cur.kick_pwm = KICK_PWM_CORRECTION*kdirection;
  }
  else
  {
    if(cur_acc*kdirection>CLOSE_TO_ZERO_ACCELERATION && (cur_speed-m_dst_speed)*kdirection>BREAK_MAX_SPEED_DIFF_WITH_ACCELERATION || (cur_speed-m_dst_speed)*kdirection>BREAK_MAX_SPEED_DIFF)
    {
      cur.is_brake=true;
      cur.kick_pwm = -BREAK_PWM_CORRECTION*kdirection;
    }
  }

  cur.correction_pwm = constrain(cur.correction_pwm, -2.0*m_pwm_limit, 2.0*m_pwm_limit);

  if(m_dst_speed == 0.0)
    cur.is_brake = true;

  float res_pwm = cur.pwm();
  is_brake = cur.is_brake;
#if 0
  Serial.print(" dst_sp=");
  Serial.print(m_dst_speed,4);
  Serial.print(" acc=");
  Serial.print(cur_acc,4);
  Serial.print(" dt=");
  Serial.print(cur.time-prev.time);
  Serial.print(" cur: ");
  cur.dump_state(Serial);
  Serial.println("");
#endif
  return  res_pwm;
}

void MotorSpeed::reset_pid()
{
  shot_t s;
  s.time = millis();
  std::fill(m_shots.begin(),m_shots.end(),s);
}

void MotorSpeed::fail_safe()
{
  m_dst_speed = 0.0;
  m_motor.brake();
  m_distance_mode = false;
  reset_pid();
}

float MotorSpeed::speed2pwm(float speed) const
{
  return m_speed2pwm * speed;
}

void MotorSpeed::set_distance(float speed, float distance)
{
  if(speed == 0.0)
    return set_speed(speed);
  
  m_dst_speed = constrain(speed, -MAX_SPEED, MAX_SPEED);
  m_distance = static_cast<int>(distance*WHEEL_PULSES_PER_METER);
  m_start_distance_tick = m_motor.get_ticks_count();
  m_distance_mode = true;
}

bool MotorSpeed::get_path(double& cur_dist) const
{
  if(m_distance_mode)
    cur_dist = (m_motor.get_ticks_count() - m_start_distance_tick) / WHEEL_PULSES_PER_METER;
  return m_distance_mode;
}

void MotorSpeed::speed_pin_isr()
{
  m_motor.speed_pin_isr();
  if(!m_distance_mode)
    return;
  
  int diff = m_motor.get_ticks_count() - m_start_distance_tick;
  int dx = (m_distance>=0) ? 1.0:-1.0;

  if(diff*dx >= m_distance*dx)
  {
    m_distance_mode = false;
    m_dst_speed = 0.0;
    m_motor.brake();
    reset_pid();
  }
}

unsigned MotorSpeed::wrap_shot_idx(unsigned idx)
{
  static_assert( (std::numeric_limits<unsigned>::max()%SHOTS_COUNT) == SHOTS_COUNT-1);
  return idx % SHOTS_COUNT;
}

bool MotorSpeed::anti_stall()
{
  shot_t& cur = m_shots[m_cur_shot];
  const shot_t& last = m_shots[wrap_shot_idx(m_cur_shot + 1)];

  if(cur.is_stalled)
    return true;
  
  if(cur.dst_speed==0 || cur.speed != 0.0  || cur.time-last.time < STALED_TRIGER_MS)
    return false;
  
  for(const shot_t& v : m_shots)
    if(v.is_stalled || v.speed != 0.0)
      return false;
  
  //Serial.println("stalled");
  m_motor.brake();

  cur.is_stalled = true;
  return true;
}

void MotorSpeed::dump_state(const String& caption, Stream& stream)
{
  float cur_speed = m_motor.get_speed_meters();
  Motor::State st = m_motor.get_state();

  if(st == Motor::st_brake && cur_speed == 0.0)
  {
    return;
  }

  stream.print(caption);
  stream.print(":");
  stream.print(" time=");
  stream.print(millis());
  stream.print(" dst_speed=");
  stream.print(m_dst_speed,4);
  stream.print(" cur_speed=");
  stream.print(cur_speed,4);
  stream.println("");
}

void MotorSpeed::shot_t::dump_state(Stream& stream)
{
  stream.printf("speed=%.4f pwm=%.4f(%.4f ; %.4f ; %.4f) brake=%d",speed, pwm(), func_pwm, correction_pwm, kick_pwm, is_brake);
}

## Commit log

2024-08-30 2 wheel platform based on esp32
2024-10-06 Implement button click and rectangle selection
2024-10-12 Add buttons using ChatGPT
2024-10-12 ChatGPT button click handler
2024-10-12 1. Prevent rectangle visible until object selection (chatGPT) 2. Prevent dragging image (chatGPT) 3. Process requests on server side 4. Prevent crash, when to_jpeg() returns None after script restart
    [http_server.py, main.py, states.py]
2024-10-13 Move buttons to right
2024-10-15 Add WiFi features. If fail connect to WiFi switch to AP mode
    [main.py]
2024-10-16 Disable wifi switch AP mode doesn't start DHCP And switch back to STA go wrong.
    [main.py]
2024-10-19 Configuring network thru python was bad idea. Add S30wifidyn which try establish sta connection, if fails switch to ap mode
    [main.py]
2024-10-27 1. Get rid of Flask, because it creates a lot of threads and to noisy 2. Implement synchronized function call in main thread. 3. Get state just after click,click_point, sel_rect requests
2024-10-27 1. Apply immediately /click /click_point /sel_rect to buttons state 2. Return state even if requests are not executed 3. Move server to 80 port
2024-11-09 Increase line width to avoid red-grey rectangles
    [http_server.py, tracker.py]
2024-11-19 pan\tilt stl model
    [case1.stl, case2.stl, pan.stl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]
2024-12-08 Parts schematic
2024-12-09 rename motor.h to mdd3a controller which was used to control dc motor
2024-12-09 Add szx11h motor controller
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2024-12-13 1. Always brake for zero speed 2. 20kHz PWM just follow controllers recommendations 3. Separate RELATIVE_MAX_SPEED because it a bit scary with full speed 4. Dump wheels state in com port to have a gl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
2024-12-21 Update 3d models 1. Base for pantilt 2. Cover for 2020 profile
    [2020_cover.blend, base.stl, base_lid.stl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]
2024-12-21 shorter screw placeholer
    [pantilt.blend]
2024-12-25 Move servo closer to the front
    [base_lid.stl, pantilt.blend]
2025-01-01 Implementation of pan-tilt tracking Doesn't work as expected yet
    [algos.py, main.py, pan_tilt.py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]
2025-01-02 Release servos when exit Measure real focus distance
2025-01-07 1. Increase camera resolution 2. Add keyboard support to control camera and movement 3. Add Pan state for mobile
2025-01-27 Avoid low power exception on shutdown
    [pan_tilt.py]
2025-02-16 PID control on pwm instead of speed
2025-02-16 Split motor_speed.h to .cpp and .h
2025-02-16 Assume we have some koef. between PWM and unloaded wheel speed. Make error correction around this value. Also introduced delays. But it doesn't look like it helps somehow. Add maximum acceleration bu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
    [motor_speed .cpp, motor_speed.h, robot.ino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]
2025-02-16 Motors control in separate thread
2025-03-08 Speed test with different masses and PWM
2025-03-13 Yet another speed control. Based on equilibrium velocity. Still not satisfied how it's work
2025-03-15 Less or more satisfied. Works pretty much the same for different loads. Like empty truck or me as a load. We don't try to adjust m_speed2pwm because it not constant even for the same environment. In 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
    The general idea now is:
    - adjust PWM slowly unless it increase the speed with any acceleration
    - add one time kick to PWM if speed remain zero
    - break if speed go to far in wrong direction or go with acceleration
    [motor_speed .cpp, motor_speed.h, robot.ino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]
2025-03-22 Increase pan/tilt insensitive zone to avoid shaking
    [pan_tilt.py]
2025-03-30 Yolo custom model track
2025-04-21 Fix nanotrack display on the screen
    [tracker.py]
2025-04-23 1. Pass correct fit to MoveTo 2. Ensure tracker still in the yolo_trackers, because self stopping algo calls YoloTrackObject::stop() 2 times.
    [algos.py, states.py, tracker.py]
2025-09-29 Kikad board of the robot
    [main_board.kicad_pcb, main_board.kicad_sch]
2025-10-12 1. Add pins header 2. Add deep sleep on low-voltage
2025-10-13 Tune voltage for another ESP module
2025-10-13 1. Reconnect 5V_CUT from GPIO2 to GPIO19. Because GPIO2 is the LED 2. Pull-up RX2 3. Figured out with VCC_ADC resistor divider 4. Change input to NPN cut transistor from 200 Om to 10K. 200 Om is way 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
    [main_board.kicad_pcb, main_board.kicad_sch]
2025-10-13 Swap the motors. Simply because it easier to connect
    [main_board.kicad_pcb, main_board.kicad_sch]
2025-10-31 Swap motors because right motor is closer to connector
    [motor_speed.h, power_managment.cpp, robot.ino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]
2025-11-16 Final scheme changes before production
    [main_board.kicad_pcb, main_board.kicad_sch]
2025-11-24 5V <-> 3.3V level shifter schematic Direct 5V on other inputs affects on ADC and we can't get correct voltage
    [level_shifter.kicad_pcb, level_shifter.kicad_sch]
2025-11-24 Smoothing voltage and add delay on low voltage sleep
2025-11-24 I don't use this N-MOSFET anymore
2025-11-25 We can't use GPIO39 for hall input, because it also VN Whenever we measure ADC on GPIO36 (VP) interrupt for GPIO39 is raised
2025-11-29 Use hall sensors to detect direction of speed
2025-11-29 Move hardware specific from speed controller directly to motor controller
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2025-11-30 Show voltage on a screen and web interface
2025-11-30 Increase a low voltage a bit, because not much energy left even to sleep with previous limit.
2025-12-13 1. Fix: sleep command should receive int parameter 2. Increase sleep duration to 5 min, because unlikely battery charge faster
    [robot.ino, robot_defs.h]
2025-12-14 Seems times updates after start. And because of previous attempt to fix it module doesn't off at all
    [http_server.py, main.py, touch_process.py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]
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2025-12-14 Need to skip few cycles to let receive the voltage and get stable image
    [telegram.py]
2025-12-16 fix params duplication for set of commands
    [telegram.py]
2025-12-20 Trying to establish p2p connection. Fails so far
    [udpv6.py]
2025-12-28 Start implementing desktop application Fix some bugs in UDP protocol
    [udp_server.py]
2025-12-31 Switch off http interface
2025-12-31 Better image flow control with ackceptance
2025-12-31 Add move camera and cart commands
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2026-01-11 1. Avoid intermediate memory allocation in pack() 2. Reduce maximim jpeg quailty and reducejpeg step to 1 to avoid skipped frames 3. Check packet inside parse() because otherwise we can't check it pr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
    [arr_change.py, udp_server.py]
2026-01-11 Pack chunk just in common pack() function to avoid additional memory allocation and copy
    [udp_server.py]
2026-02-20 Add udp_relay mode into device
2026-03-21 We don't bombard relay with packets if there is there is no answer from that side. Just send state each STATE_SEND_PERIOD ms
2026-03-21 Connect to local name first, then use relay
2026-03-21 Free mode for camera pan, tilt.
2026-04-23 1. Fix error if no local_name provided 2. Print receiving packet delay
2026-04-27 1. Add distance command 2. Add traveled distance to state output 3. State commands also prevents failSafe() 4. Increase a bit FAIL_SAFE_DELAY because bluetooth can't send state command in time
    [motor_speed.cpp, motor_speed.h, motor_zsx11h.cpp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]
2026-04-30 Add connection thru relay server Cursor code
2026-05-01 1. Different icon for relay mode (cursor) 2. Latency update in the status bar (cursor)
2026-05-01 Filter Pan and Move states (cursor)
2026-05-05 Buttons in application interface calls distance command
2026-05-07 Moved from arduino project
2026-05-08 Compare speed measurement using timer an cpu cycles method
2026-05-09 Check cpu speed deviation on different PWM
2026-05-11 1. Move to CPU cycles speed detection method 2. Increase PWM resolution to 10 bits
2026-05-17 Speed detection improvement. If we got fired the first hall sensor isr, we already can assume some speed using known delay between check_speed_timeout() calls.
2026-05-17 1. speed_correction choice was wrong for negative speed 2. Rename dx to kincrease to point if we should accelerate or brake 3. Change speed cycle delay from 50ms to 10ms and tune the parameters
    [motor_speed.cpp, robot_defs.h]
2026-05-25 Bell shape base for pan-tilt
    [base.stl, base_lid.stl, pantilt.blend]
2026-05-26 Calculate just correction in addition to main speed function
    [motor_speed.cpp, motor_speed.h]
2026-05-30 Find out that 110ms is enough to remove stalled protection of motor controller
    [speed_cycles.ino]
2026-05-30 Find out kick pwm doesn't really affect how unloaded wheel speed up from zero to 0.3m/s
    [motor_speed.cpp, robot_defs.h]
2026-05-30 Speed hangs because of MAIN_CYCLE_DELAY if we got only one hall sensor event
2026-05-30 1. Anti stall 2. Remove brake on direction change calc_pwm() works pretty well
    [motor_speed.cpp, motor_speed.h, robot_defs.h]
2026-05-30 Try active breaking by pwm
2026-05-31 We don't need detach/atach pwm pin we can just set pwm to zero
2026-05-31 Remove brake_state because noobody need it
2026-05-31 1. Add MIN_PWM to avoid motor controller zero speed protection 2. Add PWM limiter. The idea is we just limit maximum power.
    [motor_speed.cpp, motor_speed.h, motor_zsx11h.h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]
2026-06-06 Hint brake if m_dst_speed == 0
2026-06-14 cover parts rebuilt for soft plastic
    [2020_cover.blend, cover_back.stl, cover_clipsed_143.stl]
2026-07-05 Improve video streaming over mobile 1. Use 320*320 yolo image for relay mode 2. decrease quality not only by size, but if image acceptance timeout 3. Downscale image again up to 160*160 if jpeg quali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
2026-07-05 Check example how canvas draw work for RTSP connection Save ffmpeg line which actually work as a relay with mediamtx
2026-07-08 Delay between chunks to avoid losses in case of mobile network
    [udp_server.py]
2026-07-08 Remove MAX_JPEG_SIZE because chunks allows to send any size Remove constant that initialize differently server and relay mode
2026-07-08 Different chunk size for local network and relay
2026-07-18 Less timeout for relay
